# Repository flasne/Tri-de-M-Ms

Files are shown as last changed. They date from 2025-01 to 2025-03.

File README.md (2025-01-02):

# Tri-de-M-Ms

# Introduction à l'IA avec un Trieur de Couleurs pour M&M's

#Les fichiers sont sur le site [Tri-de-M-Ms](https://github.com/flasne/Tri-de-M-Ms)

## 1. Introduction Générale

- **Objectifs du cours :**
  - Comprendre les concepts de base de l'IA et leur application dans un projet concret.
- **Présentation du projet :**
  - Créer un trieur de couleurs pour des M&M's à l'aide d'un Raspberry Pi, avec une progression de techniques (classiques à IA avancée).
- **Rappel des prérequis :**
  - Notions de base en Python.
  - Compréhension des capteurs et actionneurs utilisés avec le Raspberry Pi.
  - Contexte des couleurs : spectres lumineux et perception RVB.

---

## 2. Approche Classique : Analyse des Écarts de Valeurs Mesurées

- **Principe de la méthode :**
  - Comparer les valeurs RVB mesurées par un capteur à des seuils prédéfinis pour classer les couleurs.

### Matériel nécessaire :
- Raspberry Pi.
- Capteur de couleur (TCS34725 ou équivalent).
- Servo-moteur pour trier les M&M's.

### Étapes :
1. **Mesurer les couleurs :** Exploiter le capteur pour obtenir des valeurs RVB des M&M's.
2. **Définir les seuils :** Établir une gamme de valeurs pour chaque couleur (rouge, vert, bleu, jaune).
3. **Programmer la logique conditionnelle :** Utiliser des instructions `if-else` pour diriger les M&M's vers des emplacements spécifiques.

### Limites de l'approche classique :
- Sensibilité aux variations de lumière.
- Difficulté à généraliser.

---

## 3. Introduction aux Modèles d'IA Classiques

- **Principe :**
  - Remplacer la logique conditionnelle par un modèle d'IA entraîné pour classer les couleurs.
  
### Modèles abordés :
- Régression logistique.
- Forêt aléatoire.
- k-Nearest Neighbors (k-NN).

### Étapes :
1. **Collecte de données :** Créer un dataset en mesurant des valeurs RVB et en annotant manuellement les couleurs.
2. **Entraînement des modèles :** Utiliser une bibliothèque comme `scikit-learn` pour entraîner un modèle sur les données collectées.
3. **Évaluation :** Comparer les performances des différents modèles sur des M&M's non vus pendant l'entraînement.
4. **Implémentation :** Intégrer le modèle choisi dans le programme pour trier les M&M's en temps réel.

### Discussion :
- **Avantages de l'IA sur les seuils fixes :** Meilleure adaptabilité et robustesse.

---

## 4. Exemple Avancé : Introduction au Deep Learning

- **Principe :**
  - Utiliser un réseau de neurones pour classer les couleurs avec davantage de flexibilité.

### Matériel et outils :
- Raspberry Pi (avec un accélérateur comme Google Coral pour le traitement en temps réel, si possible).
- Bibliothèque `TensorFlow` ou `PyTorch`.

### Étapes :
1. **Collecte et augmentation des données :** Capturer un dataset plus large, inclure des variations de luminosité, bruit, etc.
2. **Création d’un modèle simple :** Un réseau à plusieurs couches (MLP) pour traiter les données RVB.
3. **Entraînement :** Utiliser un ordinateur pour entraîner le modèle, puis déployer sur le Raspberry Pi.
4. **Optimisation :** Discuter des outils comme TensorFlow Lite pour optimiser le modèle pour l'embarqué.
5. **Évaluation finale :** Comparer les performances du deep learning avec les modèles classiques.

### Discussion :
- **Applications pratiques :** Tri automatisé dans l'industrie, reconnaissance d'images, domotique.
- **Limites :** Temps d'entraînement, besoin en données.

---

## 5. Conclusion et Ouverture

- **Résumé :**
  - Évolution des techniques : classique → modèles d'IA → deep learning.
  - Avantages et inconvénients de chaque approche.
- **Applications réelles :** Tri automatisé dans l'industrie, reconnaissance d'images, domotique.
- **Prolongements :** Intégrer des caméras pour détecter les formes ou textures en complément des couleurs.
- **Questions et perspectives :** Comment améliorer le modèle avec plus de données ou d'autres capteurs ?

---

## 6. Annexes et Ressources

- **Code Python :** Scripts pour chaque étape.
- **Datasets :** Exemples pour tester les modèles.
- **Références :**
  - Documentation scikit-learn.
  - Guides TensorFlow Lite.
  - Ressources pédagogiques complémentaires.

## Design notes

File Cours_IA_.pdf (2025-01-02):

| Initiation à l’intelligence artificielle. Application à un trieur de M&Ms | Animation
GIPTIC SII | Application au trieur de M&Ms | Page 1 sur 44

## Introduction à l'IA avec un trieur de couleurs pour M&M's

### 1. Introduction générale

- Objectifs du cours : Comprendre les concepts de base de l'IA et leur application dans un projet concret.
- Présentation du projet : Créer un trieur de couleurs pour des M&M's à l'aide d'un Raspberry Pi, avec une progression de techniques (classiques à IA avancée).
- Rappel des prérequis :
- Notions de base en Python.
- Compréhension de capteurs et d'actionneurs utilisés avec le Raspberry Pi.
- Contexte des couleurs : spectres lumineux et perception RVB.

### 2. Approche classique : Analyse des écarts de valeurs mesurées

Principe de la méthode : Comparer les valeurs RVB mesurées par un capteur à des seuils prédéfinis pour classer les couleurs.

- Matériel nécessaire :
- Raspberry Pi.
- Capteur de couleur (TCS34725 ou équivalent).
- Servo-moteur pour trier les M&M's.
- Étapes :
1. Mesurer les couleurs : Exploiter le capteur pour obtenir des valeurs RVB des M&M's.
2. Définir les seuils : Établir une gamme de valeurs pour chaque couleur (rouge, vert, bleu, jaune).
3. Programmer la logique conditionnelle : Utiliser des instructions if-else pour diriger les M&M's vers des emplacements spécifiques.
- Limites de l'approche classique : Sensibilité aux variations de lumière, difficulté à généraliser.

### 3. Introduction aux modèles d'IA classiques

- Principe : Remplacer la logique conditionnelle par un modèle d'IA entraîné pour classer les couleurs.
- Modèles abordés :
- Régression logistique.
- Forêt aléatoire.
- k-Nearest Neighbors (k-NN).
- Étapes :
1. Collecte de données : Créer un dataset en mesurant des valeurs RVB et en annotant manuellement les couleurs.
2. Entraînement des modèles : Utiliser une bibliothèque comme scikit-learn pour entraîner un modèle sur les données collectées.
3. Évaluation : Comparer les performances des différents modèles sur des M&M's non vus pendant l'entraînement.
4. Implémentation : Intégrer le modèle choisi dans le programme pour trier les M&M's en temps réel.
- Discussion : Avantages de l'IA sur les seuils fixes (meilleure adaptabilité, robustesse).

GIPTIC SII | Application au trieur de M&Ms | Page 2 sur 44

### 4. Exemple avancé : Introduction au deep learning

- Principe : Utiliser un réseau de neurones pour classer les couleurs avec davantage de flexibilité.
- Matériel et outils :
- Raspberry Pi (avec accélérateur comme Google Coral pour le traitement en temps réel, si possible).
- Bibliothèque TensorFlow ou PyTorch.
- Étapes :
1. Collecte et augmentation des données : Capturer un dataset plus large, inclure des variations de luminosité, bruit, etc.
2. Création d’un modèle simple : Un réseau à plusieurs couches (MLP) pour traiter les données RVB.
3. Entraînement : Utiliser un ordinateur pour entraîner le modèle, puis déployer sur le Raspberry Pi.
4. Optimisation : Discuter des outils comme TensorFlow Lite pour optimiser le modèle pour l'embarqué.
5. Évaluation finale : Comparer les performances du deep learning avec les modèles classiques.
- Discussion : Applications pratiques du deep learning et limites (temps d'entraînement, besoin en données).

### 5. Conclusion et ouverture

- Résumé :
- Évolution des techniques : classique → modèles d'IA → deep learning.
- Avantages et inconvénients de chaque approche.
- Applications réelles : Tri automatisé dans l'industrie, reconnaissance d'images, domotique.
- Prolongements : Possibilité d'intégrer des caméras pour détecter les formes ou textures en complément des couleurs.
- Questions et perspectives : Comment améliorer le modèle avec plus de données ou d'autres capteurs ?

### 6. Annexes et ressources

- Code Python pour chaque étape.
- Datasets exemples pour tester les modèles.
- Références pédagogiques et documentations (scikit-learn, TensorFlow Lite, etc.).

GIPTIC SII | Application au trieur de M&Ms | Page 3 sur 44

## 1. INTRODUCTION GENERALE

Contexte des couleurs : Spectres lumineux et perception RVB

## 1.1. La nature de la lumière et des couleurs

- La lumière visible :
La lumière est une onde électromagnétique, et la partie visible par l’œil humain correspond à une gamme de longueurs d’onde allant de 400 nm (violet) à 700 nm (rouge).
- Spectre lumineux :
Chaque couleur correspond à une longueur d'onde particulière. Par exemple :
- Violet : ~400-450 nm
- Bleu : ~450-495 nm
- Vert : ~495-570 nm
- Jaune : ~570-590 nm
- Rouge : ~620-700 nm
- Couleurs perçues :
La couleur que nous voyons est le résultat de la lumière réfléchie par un objet. Un objet jaune, par exemple, absorbe les longueurs d'onde dans le bleu et réfléchit celles correspondant au jaune.

## 1.2. La perception des couleurs par l'œil humain

- Les photorécepteurs :
L’œil humain possède trois types de cônes sensibles aux longueurs d’onde :
- Cônes L (longueurs d'onde longues, rouge)
- Cônes M (longueurs d'onde moyennes, vert)
- Cônes S (longueurs d'onde courtes, bleu)

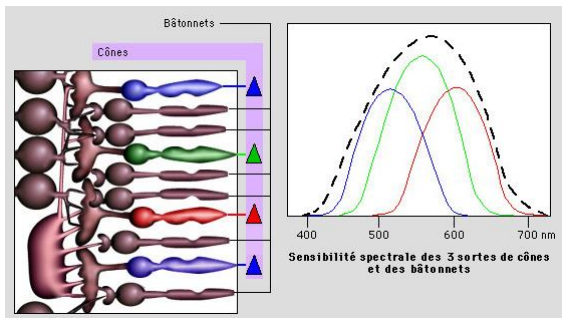
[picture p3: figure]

- Mélange additif des couleurs :
L'œil humain perçoit une couleur en combinant les signaux des cônes L, M, et S. Par exemple :
- Rouge + Vert → Jaune

GIPTIC SII | Application au trieur de M&Ms | Page 4 sur 44
- Rouge + Bleu → Magenta
- Vert + Bleu → Cyan
- Rouge + Vert + Bleu → Blanc

## 1.3. Modèle RVB (Rouge, Vert, Bleu) RGB

- Définition :
Le modèle RGB est un système de représentation des couleurs basé sur la perception humaine. Chaque couleur est définie par une combinaison de trois valeurs (R, G, B), chacune représentant l'intensité lumineuse dans une des trois bandes : rouge, vert, bleu.
- Plage des valeurs :
Typiquement, les valeurs RGB vont de 0 (aucune lumière) à 255 (intensité maximale), formant une palette de plus de 16 millions de couleurs.
Exemple :
- Rouge pur : (255, 0, 0)
- Vert pur : (0, 255, 0)
- Bleu pur : (0, 0, 255)
- Blanc : (255, 255, 255)
- Noir : (0, 0, 0)
- Applications dans le projet :
Les capteurs de couleur (comme le TCS34725) mesurent les valeurs RVB d’un objet en analysant la lumière réfléchie par celui-ci et en la décomposant en trois composantes (R, G, B).

## 1.4. Variabilité des mesures RVB

- Facteurs influençant les mesures :
- Source lumineuse : La couleur perçue peut changer selon la lumière ambiante (naturelle, LED, etc.).
- Réflectance de la surface : Les objets brillants ou mats n’interagissent pas de la même manière avec la lumière.
- Position et distance du capteur : La mesure peut varier en fonction de l’angle ou de la distance entre le capteur et l’objet.
- Importance de la calibration :
Pour garantir des mesures précises et cohérentes, il est souvent nécessaire de calibrer le capteur avec des couleurs de référence avant de commencer le tri.

GIPTIC SII | Application au trieur de M&Ms | Page 5 sur 44

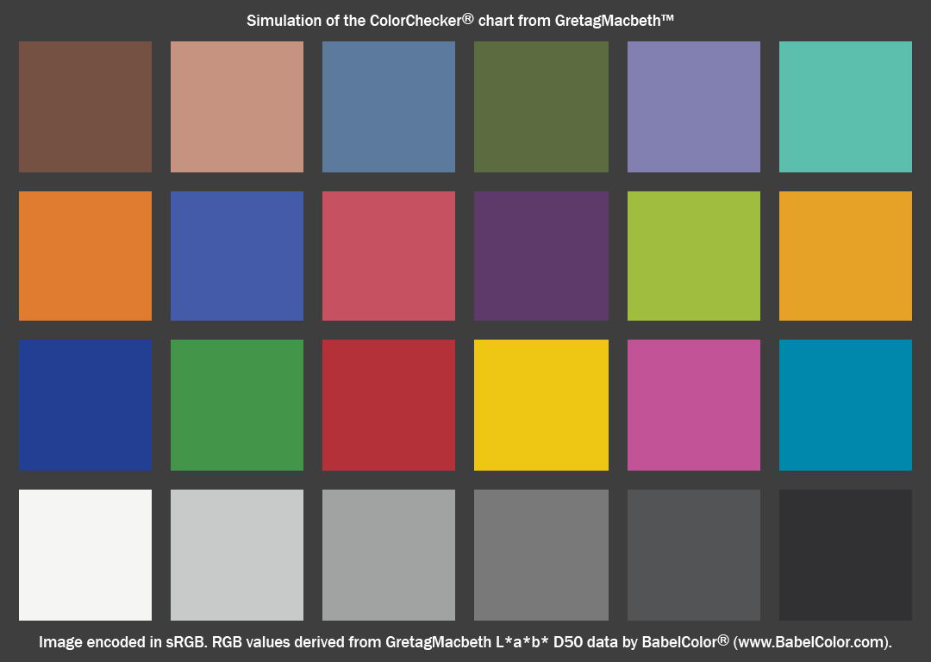
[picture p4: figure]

## 1.5. Illustration pratique pour le projet

- Exemple de mesure :

Un M&M rouge pourrait donner les valeurs approximatives suivantes :
- Rouge : 200
- Vert : 50
- Bleu : 40

Un M&M jaune, en revanche, pourrait donner :

- Rouge : 180
- Vert : 170
- Bleu : 50
- Analyse :
Les valeurs mesurées permettent de distinguer les couleurs des M&M's et de les classer en fonction de seuils ou via des modèles IA.

Fonctionnement succinct du capteur de couleur TCS34725

Le TCS34725 est un capteur de couleur populaire pour les projets électroniques, notamment avec un Raspberry Pi ou un Arduino. Voici son fonctionnement résumé :

GIPTIC SII | Application au trieur de M&Ms | Page 6 sur 44

## 1.6. Principe de base

- Détection de lumière réfléchie :
Le capteur utilise un photodétecteur pour mesurer la lumière réfléchie par un objet. Il capte les intensités lumineuses dans trois bandes spectrales principales : rouge (R), vert (G), et bleu (B), ainsi qu’une composante luminance totale (canal clair).

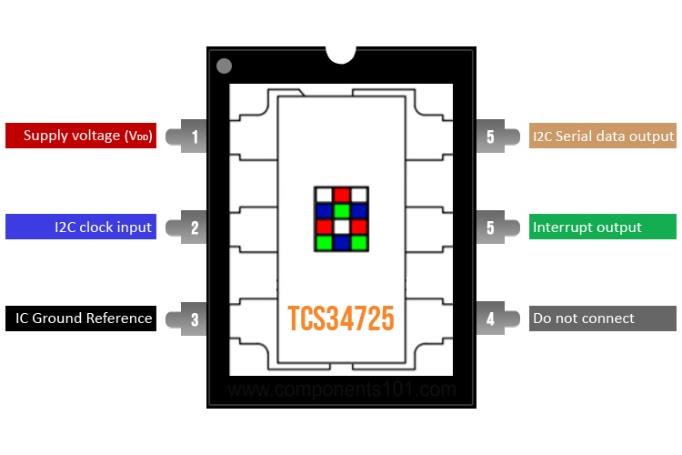
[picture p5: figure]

- Éclairage intégré :

Le TCS34725 possède une LED blanche intégrée pour fournir un éclairage constant, améliorant la précision des mesures indépendamment des conditions lumineuses ambiantes.

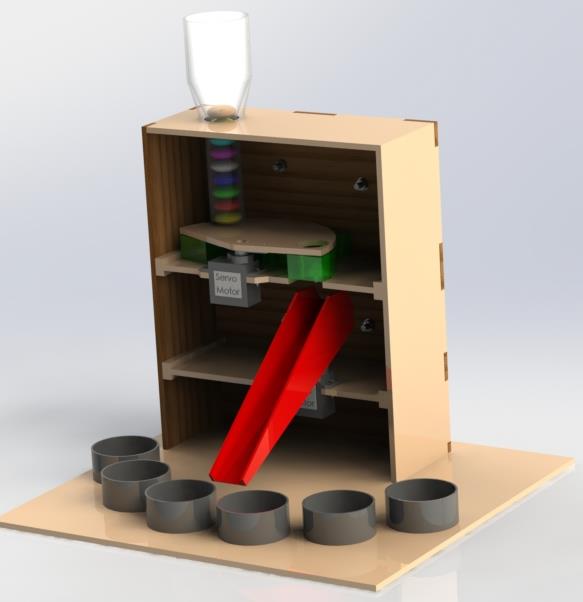
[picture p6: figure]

## 1.7. Composants principaux

- Filtre passe-bande :
Un filtre intégré isole les longueurs d'onde correspondant aux couleurs rouge, verte, et bleue.
- Photodiodes :
Chaque photodiode est dédiée à une bande de fréquence (R, G, B, et clair). Elles transforment la lumière incidente en signaux électriques proportionnels à l’intensité lumineuse.
- Convertisseur analogique-numérique (ADC) :
Le capteur convertit les signaux analogiques en valeurs numériques exploitables via un microcontrôleur ou un ordinateur (Raspberry Pi, par exemple).

GIPTIC SII | Application au trieur de M&Ms | Page 7 sur 44

## 1.8. Interface et communication

- Protocole I2C :
Le TCS34725 communique via le protocole I2C, ce qui facilite son intégration avec des
microcontrôleurs ou des
ordinateurs monocarte comme le Raspberry Pi.
- Commande logicielle :
Les bibliothèques comme Adafruit TCS34725 (en Python) simplifient son utilisation en fournissant des fonctions pour lire les valeurs
RVB et calibrer le capteur.

## 1.9. Avantages

- Compact, précis et facile à utiliser.

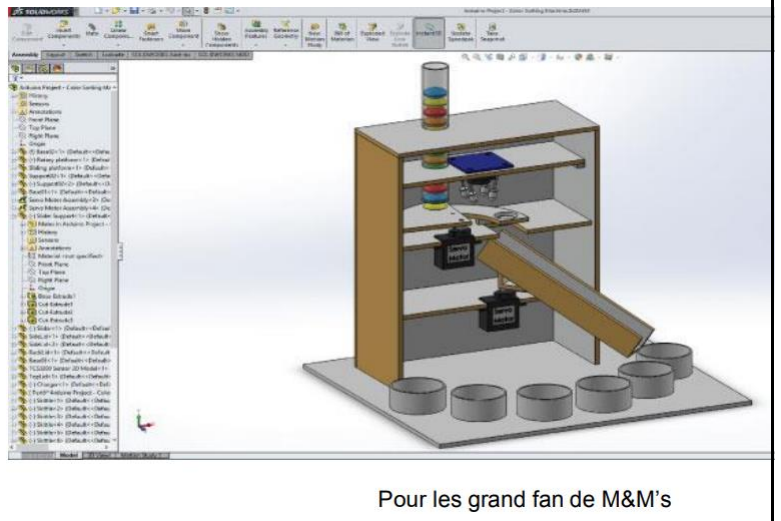
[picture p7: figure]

- LED intégrée pour garantir des mesures constantes.
- Compatible avec de nombreux environnements de développement (Arduino, Raspberry Pi).

## 1.10 Installation des paquets

pip install smbus2
sudo apt install -y python3-pyqt5 python3-opengl python -m pip install scipy
python -m pip install numpy
python -m pip install matplotlib
python -m pip install sklearn
python -m pip install pandas
pip3 install -U scikit-learn scipy matplotlib pip install pandas tensorflow scikit-learn joblib

## 2. APPROCHE CLASSIQUE : ANALYSE DES ECARTS DE VALEURS MESUREES

On utilise pour répondre au cahier des charge deux servo moteur :

Les servos sont câblés sur les sortie GPIO 17 bas et 18 haut

1. Servo 1 : avec trois positions :
- Position 1 : Chargement.
- Position 2 : Mesure.
- Position 3 : Éjection.

GIPTIC SII | Application au trieur de M&Ms | Page 8 sur 44
2. Servo 2 :
- 6 positions pour trier les M&M’s par couleur : marron, vert, orange, jaune, rouge, bleu.

Pour une meilleure gestion des servos moteurs utilisation de la librairie pigpiod pour les raspberry < P5

https://abyz.me.uk/rpi/pigpio/download.html

wget https://github.com/joan2937/pigpio/archive/master.zip unzip master.zip
cd pigpio-master
make
sudo make install

## Bus I2C

Le capteur de couleur sur le bus I2C, activer le bus I2C pour le raspberry et vérifier la présence du capteur sudo apt-get install i2c-tools
sudo i2cdetect -y 1

adresse #39 pour APDS-9960 Digital Proximity, Ambient Light, RGB and Gesture Sensor

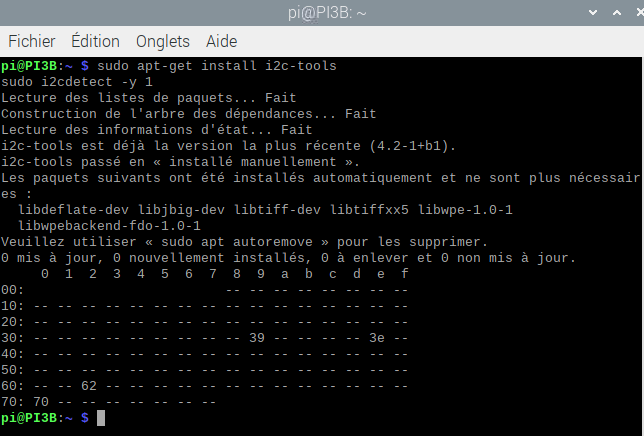
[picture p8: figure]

## 2.1 Câblage et simulation exemple en Micropython et WOKWI

GIPTIC SII | Application au trieur de M&Ms | Page 9 sur 44

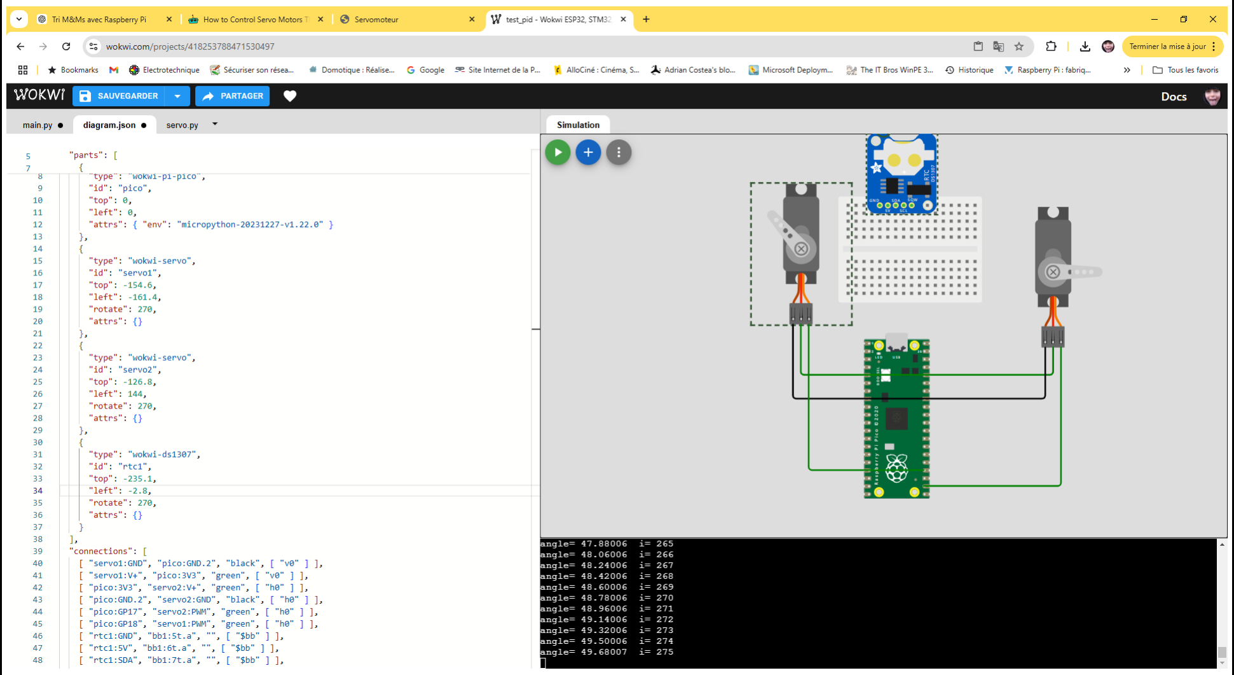
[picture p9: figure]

### 2.2 Création d’un fichier CSV pour les échantillons

Programme pour collecter des échantillons de données et générer un fichier CSV contenant les valeurs RGB mesurées pour 10 pastilles de chaque couleur. Le programme suit un cycle itératif où vous insérez les pastilles par couleur et validez chaque échantillon. Le fichier CSV sera généré après la collecte de tous les échantillons sous le nom :

couleurs_echantillons.csv

Programme Python

from gpiozero import Servo
from time import sleep
from gpiozero.pins.pigpio import PiGPIOFactory import smbus
import csv

factory = PiGPIOFactory()

servoh = Servo(18, min_pulse_width=0.56, max_pulse_width=1.85, pin_factory=factory)
servob = Servo(17, min_pulse_width=0.52, max_pulse_width=1.8 , pin_factory=factory)

# Configuration I2C

bus = smbus.SMBus(1)

GIPTIC SII | Application au trieur de M&Ms | Page 10 sur 44

SENSOR_ADDRESS = 0x39

# Définir le chemin du fichier CSV

nom_fichier = "couleurs.csv"

# Liste des couleurs et structure pour stocker les données COULEURS = ["bleu", "rouge", "vert", "marron", "jaune", "orange"] echantillons = {couleur: [] for couleur in COULEURS}

# Initialisation du capteur

def init_sensor():
bus.write_byte_data(SENSOR_ADDRESS, 0x00 | 0x80, 0x03)
bus.write_byte_data(SENSOR_ADDRESS, 0x07 | 0x80, 0x00)

# Lecture des données RGB

def read_colors():
bus.write_byte_data(SENSOR_ADDRESS, 0x00 | 0x80, 0x03)
sleep(0.5)
data = bus.read_i2c_block_data(SENSOR_ADDRESS, 0x10 | 0x80, 8)
green = data[1] * 256 + data[0]
red = data[3] * 256 + data[2]
blue = data[5] * 256 + data[4]

# ajustement pour fond noir red -= 19.00

green -= 35
blue -= 16

return red, green, blue

# Collecte des données pour une couleur spécifique

def collect_sample(couleur, num_samples=10): print(f"Insérez des pastilles de couleur '{couleur}'.") for i in range(num_samples):
print(f"Mesure {i + 1}/{num_samples} pour {couleur}.") print("Position de mesure...")
servoh.mid()
sleep(1)
red, green, blue = read_colors() echantillons[couleur].append((red, green, blue)) print(f"R: {red}, G: {green}, B: {blue} enregistré pour {couleur}.")

print("Position de dechargement...")
servoh.max()
sleep(1)

print("Position de chargement...") servoh.min()

GIPTIC SII | Application au trieur de M&Ms | Page 11 sur 44

sleep(3)

# Enregistrement des données dans un fichier CSV

def save_to_csv():
with open(nom_fichier, 'w', newline='', encoding='utf-8') as fichier_csv:
file = csv.writer(fichier_csv)
file.writerow(["Couleur", "Red", "Green", "Blue"]) # En-têtes for couleur, samples in echantillons.items():
for red, green, blue in samples:
file.writerow([couleur, red, green, blue]) print(f"Données enregistrées dans {nom_fichier}.")

# Programme principal

def main():
try:
init_sensor()
servoh.mid()
servob.mid()
for couleur in COULEURS:
collect_sample(couleur)
save_to_csv()
except KeyboardInterrupt:
print("Programme interrompu.") finally:
servoh.value = None
servob.value = None
print("Servos désactivés. Fin du programme.")

if __name__ == "__main__": main()

Fonctionnement

1. Initialisation :
- Le capteur et les servos sont initialisés dans les positions par défaut.
2. Collecte des Échantillons :
- Pour chaque couleur dans la liste COULEURS, le programme lit les données RGB pour 10 pastilles (ou une valeur ajustable dans num_samples).
- Entre chaque lecture, le servo horizontal (servoh) est déplacé pour simuler la position de mesure de déchargement et de chargement.
3. Enregistrement des Données :
- Une fois toutes les pastilles mesurées, les données sont enregistrées dans un fichier CSV avec des colonnes pour la couleur et les valeurs RGB.
4. Arrêt Sécurisé :
- Les servos sont désactivés et retournent à leur état neutre à la fin ou en cas d'interruption.

Détermination des plages de couleurs à partir des échantillons

GIPTIC SII | Application au trieur de M&Ms | Page 12 sur 44

Programme Python

import csv

# Fonction pour calculer les plages de variation des couleurs def calculate_color_ranges(file_path):

color_data = {}

# Lecture du fichier CSV

with open(file_path, 'r', encoding='utf-8') as csvfile: reader = csv.reader(csvfile)
next(reader) # Ignorer les en-têtes
for row in reader:
r, g, b, color = float(row[0]), float(row[1]), float(row[2]), row[3]
if color not in color_data:
color_data[color] = {"R": [], "G": [], "B": []} color_data[color]["R"].append(r) color_data[color]["G"].append(g) color_data[color]["B"].append(b)

# Calcul des plages pour chaque couleur color_ranges = {}

for color, channels in color_data.items(): color_ranges[color] = {
"R": (min(channels["R"]), max(channels["R"])), "G": (min(channels["G"]), max(channels["G"])), "B": (min(channels["B"]), max(channels["B"])) }

return color_ranges

# Fonction principale

def main():
file_path = "couleurs_echantillons.csv" # Remplacez par le chemin de votre fichier CSV
color_ranges = calculate_color_ranges(file_path)

print("Plages de variation des couleurs :")
for color, ranges in color_ranges.items(): print(f"{color.capitalize()} :")
print(f" | R (Rouge) : {ranges['R']}")
print(f" | G (Vert) | : {ranges['G']}")
print(f" | B (Bleu) | : {ranges['B']}")

# Exécution du script

if __name__ == "__main__": main()

GIPTIC SII | Application au trieur de M&Ms | Page 13 sur 44

Fonctionnement

- Lecture des données CSV :
Le fichier CSV est lu ligne par ligne, et les valeurs RGB associées à chaque couleur sont stockées dans un dictionnaire.
- Calcul des plages de variation :
Pour chaque couleur, les valeurs minimales et maximales de R, G et B sont déterminées.
- Affichage des résultats :
Les plages de variation pour chaque couleur sont imprimées de manière lisible.

Résultat
| R | | G | | B
| min | max | min | max | min | max
Color
bleu | 0.0 | 1.0 | 0.0 | 1.0 | 4.0 | 5.0
jaune | 10.0 | 12.0 | 10.0 | 12.0 | 2.0 | 2.0
marron | 1.0 | 1.0 | -2.0 | -1.0 | 0.0 | 0.0
orange | 8.0 | 10.0 | 3.0 | 4.0 | 1.0 | 1.0
rouge | 6.0 | 7.0 | 0.0 | 1.0 | 0.0 | 1.0
vert | 1.0 | 2.0 | 4.0 | 5.0 | 2.0 | 2.0

Utilisation

COLOR_RANGES = {
"bleu": [(0.0, 0.0), (1.0, 2.0), (4.0, 5.0)], "rouge": [(6.0, 7.0), (0.0, 1.0), (1.0, 1.0)], "vert": [(2.0, 2.0), (5.0, 6.0), (2.0, 2.0)], "marron": [(0.0, 1.0), (-1.0, -1.0), (0.0, 1.0)], "jaune": [(10.0, 12.0), (10.0, 13.0), (2.0, 3.0)], "orange": [(9.0, 11.0), (4.0, 5.0), (1.0, 2.0)], }

Réalisation du programme de tri en prenant en compte des variations avec une pondération de 1

Programme Python

'''
lancer

sudo pigpiod

avant
'''

from gpiozero import Servo

GIPTIC SII | Application au trieur de M&Ms | Page 14 sur 44

from time import sleep

from gpiozero.pins.pigpio import PiGPIOFactory

import smbus
import time
import csv
import joblib

factory = PiGPIOFactory()

servoh = Servo(18, min_pulse_width=0.56/1000, max_pulse_width=1.85/1000, pin_factory=factory) servob = Servo(17, min_pulse_width=0.52/1000, max_pulse_width=1.8/1000, pin_factory=factory)

servob_POSITIONS = {
"marron": -0.3, | # Position pour marron
"vert": 0.6, | # Position pour vert
"orange": -0.95, | # Position pour orange
"jaune": -0.7, | # Position pour jaune
"rouge": 0.1, | # Position pour rouge
"bleu": 0.9 | # Position pour bleu
}

COLOR_RANGES = {
"bleu": [(0.0, 0.0), (1.0, 2.0), (4.0, 5.0)], "rouge": [(6.0, 7.0), (0.0, 1.0), (1.0, 1.0)], "vert": [(2.0, 2.0), (5.0, 6.0), (2.0, 2.0)], "marron": [(0.0, 1.0), (-1.0, -1.0), (0.0, 1.0)], "jaune": [(10.0, 12.0), (10.0, 13.0), (2.0, 3.0)], "orange": [(9.0, 11.0), (4.0, 5.0), (1.0, 2.0)], }

# Get I2C bus

bus = smbus.SMBus(1)

# Initialisation du capteur def init_sensor():

# Initialisation du capteur

# TCS3414 address, 0x39(57)

# Select control register, 0x00(00), with Command register, 0x80(128)

# | 0x03(03) | Power ON, ADC enable

bus.write_byte_data(0x39, 0x00 | 0x80, 0x03)

GIPTIC SII | Application au trieur de M&Ms | Page 15 sur 44

# Lecture des données de couleur

def read_colors():
global rang
bus.write_byte_data(0x39, 0x00 | 0x80, 0x03)
# TCS3414 address, 0x39(57)

# Select gain register, 0x07(07), with Command register, 0x80(128)

# | 0x00(00) | Gain : 1x, Prescaler Mode = Divide by 1

bus.write_byte_data(0x39, 0x07 | 0x80, 0x00)
time.sleep(0.5)
# TCS3414 address, 0x39(57)

# Read data back from 0x10(16), 8 bytes, with Command register, 0x80(128)

# Green LSB, Green MSB, Red LSB, Red MSB

# Blue LSB, Blue MSB, cData LSB, cData MSB

data = bus.read_i2c_block_data(0x39, 0x10 | 0x80, 8)
# Convert the data

green = data[1] * 256 + data[0]
red = data[3] * 256 + data[2]
blue = data[5] * 256 + data[4]
cData = data[7] * 256 + data[6]
# Calculate luminance

luminance = (-0.32466 * red) + (1.57837 * green) + (-0.73191 * blue)

red -= 19.00
green -= 35.00
blue -= 16.00

return cData, red, green, blue

# Déterminer la couleur dominante def detect_color():

_, r, g, b = read_colors()
print(f"R: {r}, G: {g}, B: {b}")
tolerance = 1
for color, (r_range, g_range, b_range) in COLOR_RANGES.items(): if (
(r_range[0] - tolerance) <= r <= (r_range[1] + tolerance) and
(g_range[0] - tolerance) <= g <= (g_range[1] + tolerance) and
(b_range[0] - tolerance) <= b <= (b_range[1] + tolerance)
):
return color
return "inconnu"

GIPTIC SII | Application au trieur de M&Ms | Page 16 sur 44

# Trier les M&M’s

def tri_m_and_ms():
while True:
print("Passage en position de chargement...") servoh.min()
sleep(1)
print("Passage en position de mesure...") servoh.mid()
couleur = detect_color()
print(f"Couleur détectée : {couleur}")
# Pause pour éviter des lectures rapides sleep(1)

if couleur in servob_POSITIONS:
print(f"Tri pour {couleur}...") servob.value = servob_POSITIONS[couleur] #control_servo(SERVO1_GPIO, SERVO1_POSITIONS["ejection"]) # Éjection après tri sleep(0.5)
servoh.max()
else:
print("Couleur inconnue, ignorer l'objet") # Pause pour éviter des lectures rapides sleep(1)
servob.value = 0

# Programme principal

print("Start in the middle") servoh.mid()
servob.mid()
rang=1
try:
init_sensor()
tri_m_and_ms()
except KeyboardInterrupt:
print("Arrêt du programme.")

Fonctionnement

1. Servo 1 :
- Change entre 3 positions (chargement, mesure, éjection) pour gérer le flux des M&M’s.
- Les angles pour chaque position sont définis dans max mid et min.
2. Servo 2 :
- Positionné selon la couleur détectée : marron, vert, orange, jaune, rouge, ou bleu.
- Les angles pour chaque couleur sont définis dans SERVO2_POSITIONS.
3. Détection des couleurs :

GIPTIC SII | Application au trieur de M&Ms | Page 17 sur 44
- Les couleurs sont détectées en comparant les valeurs de rouge, vert et bleu. Des seuils sont définis pour certaines couleurs complexes comme jaune, orange ou marron.
4. Tri :
- Le premier servo gère le déplacement des M&M’s entre les étapes.
- Le second servo place les M&M’s dans le compartiment correspondant.

Ajustements et Tests

- Calibrage des seuils de couleur : Ajustez les seuils selon les valeurs spécifiques des couleurs obtenues par votre capteur.
- Angles des servos : Modifiez les valeurs pour les adapter à votre configuration matérielle.

Constations avec une tolérance de :

### 0 les couleurs ont du mal à être détectées en fonction des variations d’éclairage

### 1 le tri est parfait aucune erreur, fin de la manipe (non !)

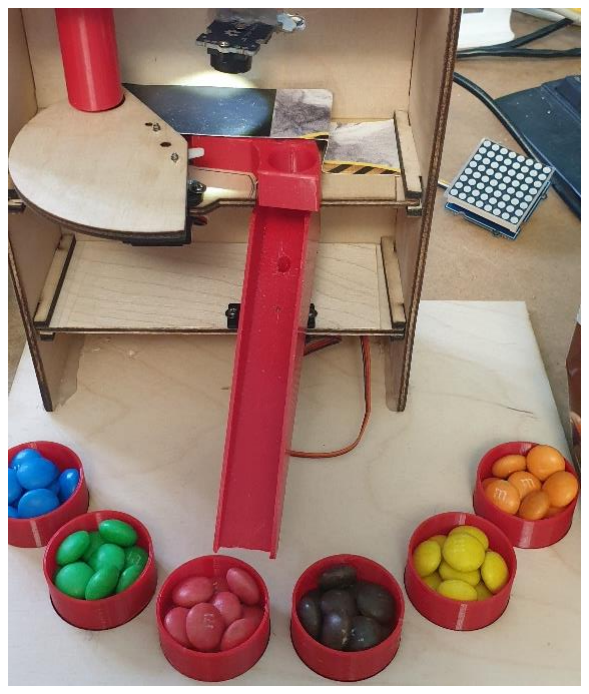
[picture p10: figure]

Avec une tolérance de 2 il y a une confusion entre les bleus et vert et entre les rouges et oranges.

GIPTIC SII | Application au trieur de M&Ms | Page 18 sur 44

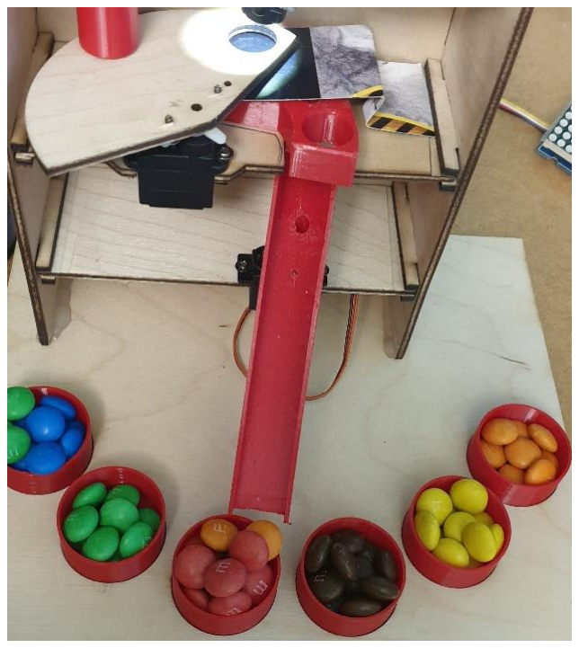
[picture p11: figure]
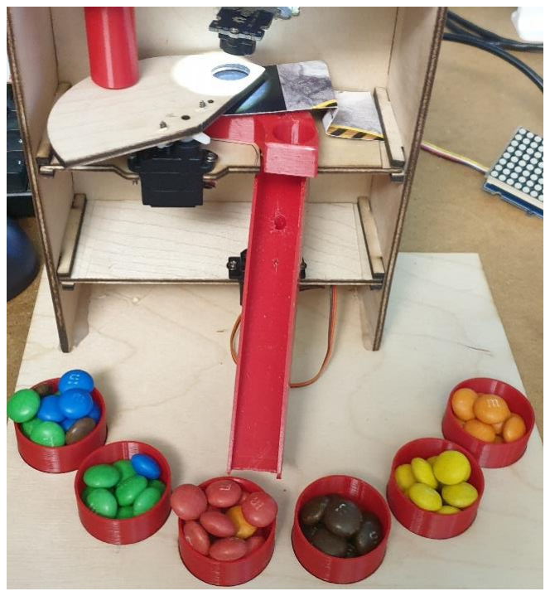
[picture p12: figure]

## 3. INTRODUCTION AUX MODELES D'IA CLASSIQUES

- 3.1 Principe :

Remplacer la logique conditionnelle par un modèle d'IA entraîné pour classer les couleurs.

- 3.2 Modèles abordés :
- Régression logistique. LR
- Forêt aléatoire.
- k-Nearest Neighbors (k-NN).

### 3.2.1. Régression logistique

Principe

- La régression logistique est un modèle statistique utilisé pour résoudre des problèmes de classification binaire ou multi-classes.
- Fonctionnement : Elle modélise la probabilité qu'une observation appartienne à une classe donnée en utilisant une fonction logistique (sigmoïde).
- Sortie : Les probabilités que l'entrée appartienne à chaque classe. La classe avec la plus grande probabilité est choisie.

Avantages

- Simplicité, rapidité, facile à implémenter.
- Bonne performance sur des données linéairement séparables.

GIPTIC SII | Application au trieur de M&Ms | Page 19 sur 44

Inconvénients

- Ne gère pas bien les relations non linéaires entre les caractéristiques.
- Sensible aux caractéristiques fortement corrélées.

### 3.2.2. Forêt aléatoire (Random Forest)

Principe

- La forêt aléatoire est un ensemble de plusieurs arbres de décision, chacun entraîné sur un sous-ensemble aléatoire des données (méthode de bootstrap) et un sous-ensemble aléatoire des caractéristiques.
- Fonctionnement : Chaque arbre vote pour une classe, et la classe majoritaire est choisie comme prédiction.

Étapes principales

1. Création des arbres :
- Les arbres sont créés en sélectionnant un sous-ensemble aléatoire des échantillons et des caractéristiques.
- Chaque arbre est construit de manière indépendante.
2. Prédiction : Lorsqu'un M&M est mesuré, chaque arbre effectue une prédiction. La classe finale est celle qui obtient le plus de votes.
3. Importance des caractéristiques : La forêt aléatoire peut également identifier quelles caractéristiques (R, G, B) sont les plus importantes pour la classification.

Avantages

- Robuste aux sur-apprentissages grâce à l'agrégation.
- Peut modéliser des relations complexes entre les caractéristiques.
- Pas besoin de normaliser les données d'entrée.

Inconvénients

- Plus lent que des modèles simples comme la régression logistique.
- Moins interprétable qu'un seul arbre de décision.

### 3.2.3. k-Nearest Neighbors (k-NN)

Principe

- Le k-NN est un modèle basé sur les instances. Il classe un nouvel échantillon en fonction des k échantillons les plus proches dans les données d'entraînement.
- Fonctionnement : Il calcule les distances entre l'échantillon à classer et toutes les observations de l'ensemble d'entraînement, puis vote pour la classe la plus fréquente parmi les kkk plus proches voisins.

Étapes principales

GIPTIC SII | Application au trieur de M&Ms | Page 20 sur 44
1. Choix de kkk : kkk est un hyperparamètre qui détermine le nombre de voisins à considérer. Des valeurs courantes sont 3, 5 ou 7.
2. Distance : La distance est souvent calculée à l’aide de la distance euclidienne : d=(R1−R2)2+(G1−G2)2+(B1−B2)2d = \sqrt{(R_1 - R_2)^2 + (G_1 - G_2)^2 + (B_1 -B_2)^2}d=(R1−R2)2+(G1−G2)2+(B1−B2)2
3. Classification : Les kkk voisins les plus proches sont identifiés, et l’étiquette majoritaire est attribuée.

Avantages

- Facile à comprendre et à implémenter.
- Aucune phase d’entraînement explicite, ce qui le rend très rapide en préparation.

Inconvénients

- Coût computationnel élevé pour les prédictions sur de grands ensembles de données (doit calculer la distance avec toutes les instances).
- Sensible à l’échelle des caractéristiques (les données doivent être normalisées si les échelles diffèrent).

Conclusion

- Régression logistique : Utilisée en première approche si les données sont simples et bien séparées.
- Forêt aléatoire : Idéal pour des problèmes plus complexes avec des interactions entre les caractéristiques.
- k-NN : Bon pour débuter ou si le jeu de données est petit, mais moins adapté pour des ensembles volumineux.

Ces trois modèles permettent une introduction progressive à l’IA et montrent comment des approches différentes peuvent résoudre un même problème de classification.

On peut tester également

LDA
Naïve Bayes
SVM

### 3.2.4 Analyse discriminante linéaire (LDA)

- Classe utilisée : LinearDiscriminantAnalysis
- Principe : LDA trouve des combinaisons linéaires de caractéristiques qui maximisent la séparation entre les classes.
- Avantage : Convient aux problèmes où les distributions des classes suivent une loi normale.

GIPTIC SII | Application au trieur de M&Ms | Page 21 sur 44
- Utilisation : Bonne alternative à la régression logistique lorsque les classes sont bien séparées.

### 3.2.5 Machine à vecteurs de support (SVM)

- Classe utilisée : SVC
- Gamma : Détermine l’influence d’un seul point d’entraînement. Avec gamma='auto', cette influence est ajustée automatiquement.
- Principe : Cherche à maximiser la marge entre les classes en utilisant des hyperplans. Peut être étendu à des problèmes non linéaires avec des noyaux (kernel).
- Avantage : Performant pour les données complexes.
- Inconvénient : Lent pour les grands jeux de données.

### 3.2.6 Naïve Bayes (NB)

- Classe utilisée : GaussianNB
- Principe : Utilise le théorème de Bayes en supposant que les caractéristiques sont indépendantes (hypothèse naïve).
- Particularité : Convient aux données où chaque classe suit une distribution gaussienne.
- Avantage : Rapide et performant pour des données simples.
- Inconvénient : Hypothèse d'indépendance souvent irréaliste.

Résumé : Quand utiliser quel modèle ?

Modèle | Complexité | Données linéaires | Données non
linéaires | Interprétabilité Rapidité
Régression logistique Faible | Oui | Non | Élevée | Rapide
LDA | Moyenne | Oui | Non | Moyenne | Moyenne
k-NN | Faible | Oui | Oui | Moyenne | Lent
Arbre de décision | Moyenne | Oui | Oui | Élevée | Moyenne
Naïve Bayes | Faible | Oui | Non | Moyenne | Rapide
SVM | Élevée | Oui | Oui (avec noyaux) Faible | Lent

Ces modèles permettent une large exploration des approches supervisées pour différents types de données et contraintes.

### 3.3. Quatre étapes à réaliser :

1. Collecte de données : Créer un dataset en mesurant des valeurs RVB et en annotant manuellement les couleurs.
2. Entraînement des modèles : Utiliser une bibliothèque comme scikit-learn pour entraîner un modèle sur les données collectées.
3. Évaluation : Comparer les performances des différents modèles sur des M&M's non vus pendant l'entraînement.

GIPTIC SII | Application au trieur de M&Ms | Page 22 sur 44
4. Implémentation : Intégrer le modèle choisi dans le programme pour trier les M&M's en temps réel.

Etape N°1 collecte des données

Voir 2.2 Création d’un fichier CSV pour les échantillons

Etape N°2 Entraînement des modèles

On choisit six modèles LDA, LR, KNN, CART, NB, et SVM

Réalisation du programme en python Apprentissage_Ai

import pandas as pd
from pandas.plotting import scatter_matrix
from matplotlib import pyplot as plt
from sklearn.model_selection import train_test_split, cross_val_score, StratifiedKFold
from sklearn.linear_model import LogisticRegression
from sklearn.tree import DecisionTreeClassifier
from sklearn.neighbors import KNeighborsClassifier
from sklearn.discriminant_analysis import LinearDiscriminantAnalysis from sklearn.naive_bayes import GaussianNB
from sklearn.svm import SVC
from sklearn.metrics import classification_report, confusion_matrix, accuracy_score
from sklearn.preprocessing import LabelEncoder
import joblib

# === 1. Chargement et exploration des données ===

# Chargement du dataset

file_path = 'couleurs.csv' # Remplacez par le chemin correct try:
dataset = pd.read_csv(file_path)
print("Dataset loaded successfully.")
except FileNotFoundError:
print(f"Error: The file '{file_path}' was not found.") exit()

# Dimensions du dataset

print("Dataset dimensions:", dataset.shape)

# Aperçu des premières lignes

print("First 5 rows:\n", dataset.head())

# Statistiques descriptives

print("Descriptive statistics:\n", dataset.describe())

# Matrice de dispersion des variables

GIPTIC SII | Application au trieur de M&Ms | Page 23 sur 44

scatter_matrix(dataset)
plt.title("Scatter Matrix of Dataset") plt.show()

# === 2. Préparation des données ===

# Séparation des caractéristiques (RVB) et des labels (classe des couleurs)

X = dataset.iloc[:, :3].values | # Colonnes RVB
Y = dataset.iloc[:, 3].values | # Classe de couleur

# Encodage des labels (classes des couleurs) label_encoder = LabelEncoder()

Y_encoded = label_encoder.fit_transform(Y)

# Séparation des données en ensembles d'entraînement et de validation X_train, X_validation, Y_train, Y_validation = train_test_split(

X, Y_encoded, test_size=0.30, random_state=1
)

# === 3. Définition et évaluation des modèles ===

# Liste des modèles à tester

models = [
('LR', LogisticRegression(solver='liblinear', multi_class='ovr')), ('LDA', LinearDiscriminantAnalysis()),
('KNN', KNeighborsClassifier()),
('CART', DecisionTreeClassifier()),
('NB', GaussianNB()),
('SVM', SVC(gamma='auto'))
]

# Comparaison des modèles

results = []
names = []
print("\nModel Evaluation Results:")
for name, model in models:
kfold = StratifiedKFold(n_splits=7, random_state=1, shuffle=True) cv_results = cross_val_score(model, X_train, Y_train, cv=kfold, scoring='accuracy')
results.append(cv_results)
names.append(name)
print(f"{name}: {cv_results.mean():.6f} ({cv_results.std():.6f})")

# Visualisation des performances

plt.boxplot(results, labels=names)
plt.title('Algorithm Comparison') plt.ylabel('Accuracy')
plt.show()

GIPTIC SII | Application au trieur de M&Ms | Page 24 sur 44

# === 4. Entraînement, prédictions et sauvegarde des modèles ===

# Fonction utilitaire pour entraîner, prédire et sauvegarder un modèle def train_and_save_model(model, model_name, X_train, Y_train, X_validation, Y_validation, label_encoder):

model.fit(X_train, Y_train)
predictions = model.predict(X_validation)

# Sauvegarde du modèle et de l'encodeur

joblib.dump(model, f'{model_name}.pkl') joblib.dump(label_encoder, f'label_encoder_{model_name}.pkl')

# Évaluation des performances

print(f"\n=== Results for {model_name} ===") print("Accuracy:", accuracy_score(Y_validation, predictions)) print("Confusion Matrix:\n", confusion_matrix(Y_validation, predictions))
print("Classification Report:\n", classification_report(Y_validation, predictions))

# Entraînement et sauvegarde pour chaque modèle

for name, model in models:
train_and_save_model(model, name, X_train, Y_train, X_validation, Y_validation, label_encoder)

# === Fin du programme ===

print("All models trained and saved successfully.")
1. Chargement des données : Ajout de gestion d'erreur pour s'assurer que le fichier CSV existe avant de continuer.
2. Exploration des données : Ajout d'une matrice de dispersion pour visualiser les relations entre les caractéristiques.
3. Préparation des données : Utilisation explicite de iloc pour séparer les caractéristiques et les labels.
4. Comparaison des modèles : Résultats affichés avec moyenne et écart type. Les graphiques de comparaison sont ajoutés.
5. Entraînement et sauvegarde : Fonction utilitaire pour éviter la duplication de code, avec des évaluations détaillées pour chaque modèle.

Les résultats sont les suivants

LR : 1.000000 (0.000000)
LDA: 1.000000 (0.000000)
KNN: 1.000000 (0.000000)
CART: 0.976190 (0.058321)
NB: 0.952381 (0.075292)

GIPTIC SII | Application au trieur de M&Ms | Page 25 sur 44

SVM: 1.000000 (0.000000)

Matrice de dispersion des variables | Visualisation des performances

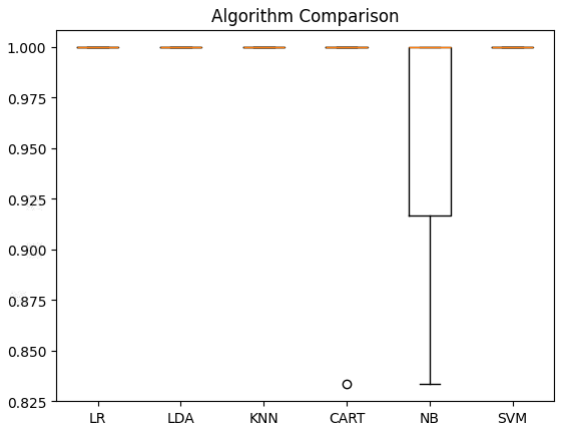
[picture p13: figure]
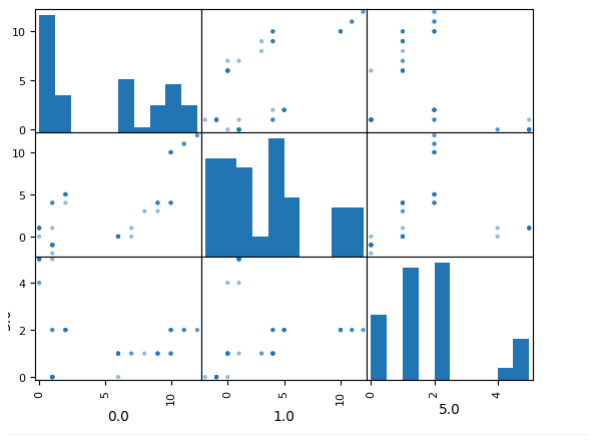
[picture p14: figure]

Les résultats affichés montrent une excellente performance des modèles testés sur le jeu de données.

### 3.4. Performances des modèles :

- Régression Logistique (LR) :
- Score moyen d'exactitude (accuracy) : 1.000000 avec écart-type 0.000000.
- Cela signifie que le modèle a classé toutes les instances correctement, sans variation dans les résultats.
- Analyse Discriminante Linéaire (LDA) :
- Score d'exactitude : 1.000000 (0.000000).
- Comme pour LR, ce modèle est parfait sur ce jeu de données.
- k-Nearest Neighbors (KNN) :
- Score d'exactitude : 1.000000 (0.000000).
- Ce modèle, basé sur les voisins les plus proches, a également obtenu une performance parfaite.
- Arbre de Décision (CART) :
- Score moyen : 0.976190 avec un écart-type de 0.058321.
- Ce modèle a montré une très légère baisse de performance et une variabilité dans les prédictions, probablement en raison de la structure de l'arbre ou de petites erreurs de classification.
- Naïve Bayes (NB) :
- Score moyen : 0.952381 avec un écart-type de 0.075292.
- Ce modèle montre une précision un peu plus faible, probablement due à l'hypothèse d'indépendance entre les caractéristiques qui n'est pas totalement respectée.
- Support Vector Machines (SVM) :
- Score moyen : 1.000000 (0.000000).
- Performances parfaites, confirmant la capacité des SVM à bien séparer les données.

### 3.5. Analyse des métriques globales :

GIPTIC SII | Application au trieur de M&Ms | Page 26 sur 44
- Accuracy globale : 1.0
- Cela signifie que toutes les instances du jeu de test ont été correctement classées par le modèle final utilisé.

Matrice de confusion :
[2 0 0 0 0 0]
[0 4 0 0 0 0]
[0 0 4 0 0 0]
[0 0 0 3 0 0]
[0 0 0 0 1 0]
[0 0 0 0 0 4]
- Chaque case de la diagonale (par ex., 2 pour la classe 0, 4 pour la classe 1, etc.) montre que toutes les instances de chaque classe ont été correctement prédites.
- L'absence de valeurs hors de la diagonale indique qu'il n'y a eu aucune erreur de classification.
4. Rapport de classification :
| precision | recall | f1-score | support
0 | 1.00 | 1.00 | 1.00 | 2
1 | 1.00 | 1.00 | 1.00 | 4
2 | 1.00 | 1.00 | 1.00 | 4
3 | 1.00 | 1.00 | 1.00 | 3
4 | 1.00 | 1.00 | 1.00 | 1
5 | 1.00 | 1.00 | 1.00 | 4
- Precision, Recall et F1-score :
- Tous les scores sont à 1.00, ce qui reflète une classification parfaite.
- Support : Le nombre d'échantillons par classe (ex. 2 pour la classe 0, 4 pour la classe 1, etc.).

Conclusions :

1. Performance globale :
- Les modèles LR, LDA, KNN et SVM ont montré une précision parfaite (accuracy = 1.0).
- CART et NB ont légèrement moins bien performé, mais restent très proches d'une classification parfaite.
2. Robustesse :
- L'absence d'erreurs dans la matrice de confusion et la cohérence des scores (précision, rappel, F1-score) montrent que les modèles gèrent bien ce jeu de données.
3. Limites potentielles :
- Les performances parfaites pourraient indiquer un surapprentissage si le jeu de données est trop simple ou pas assez diversifié.
- Il serait important de tester ces modèles sur un jeu de données plus varié ou réaliste pour évaluer leur robustesse dans des situations réelles.
4. Choix du modèle :
- Si les ressources sont limitées, LR ou KNN sont simples et performants.
- Pour des applications nécessitant une plus grande adaptabilité, SVM ou CART pourraient être envisagés.

### 3.6 Réalisation du programme en python de tri en fonction des prédictions Tri_Ai

GIPTIC SII | Application au trieur de M&Ms | Page 27 sur 44

from gpiozero import Servo
from time import sleep
from gpiozero.pins.pigpio import PiGPIOFactory import smbus
import time
import csv
import joblib
import pandas as pd

# Configuration des servos avec la bibliothèque GPIOZero et PiGPIOFactory

factory = PiGPIOFactory()

servoh = Servo(18, min_pulse_width=0.56/1000, max_pulse_width=1.85/1000, pin_factory=factory) servob = Servo(17, min_pulse_width=0.52/1000, max_pulse_width=1.8/1000, pin_factory=factory)

# Charger le modèle et le label encoder

modele = joblib.load('LR.pkl')
label_encoder = joblib.load('label_encoder_LR.pkl')

# Définir les positions des servos

servoh_POSITIONS = {
"chargement": 0.56/1000, | # Position de chargement
"mesure": 0.645/1000, | # Position de mesure
"ejection": 1.85/1000 | # Position d'éjection
}

servob_POSITIONS = {
"jaune": -0.95, | # Position pour jaune
"marron": -0.3, | # Position pour marron
"rouge": 0.1, | # Position pour rouge
"orange": -0.7, | # Position pour orange
"vert": 0.6, | # Position pour vert
"bleu": 0.98 | # Position pour bleu
}

# Configuration du bus I2C

bus = smbus.SMBus(1)

# Initialisation du capteur de couleur

def init_sensor():
"""Initialisation du capteur TCS3414."""
bus.write_byte_data(0x39, 0x00 | 0x80, 0x03)

# Lecture des données de couleur

def read_colors():

GIPTIC SII | Application au trieur de M&Ms | Page 28 sur 44

"""Lit les valeurs RGB et de luminosité à partir du capteur TCS3414."""
bus.write_byte_data(0x39, 0x00 | 0x80, 0x03)
bus.write_byte_data(0x39, 0x07 | 0x80, 0x00)
time.sleep(0.5)
data = bus.read_i2c_block_data(0x39, 0x10 | 0x80, 8)
green = data[1] * 256 + data[0]
red = data[3] * 256 + data[2]
blue = data[5] * 256 + data[4]
cData = data[7] * 256 + data[6]

red -= 19
green -= 33
blue -= 16

return cData, red, green, blue

# Déterminer la couleur dominante

def detect_color():
"""Utilise le modèle pour prédire la couleur à partir des valeurs RGB."""
_, red, green, blue = read_colors()
print(f"R: {red}, G: {green}, B: {blue}")

nouvelle_couleur = pd.DataFrame([[red, green, blue]], columns=["Red", "Green", "Blue"])
couleur_encoded = modele.predict(nouvelle_couleur)
couleur = label_encoder.inverse_transform([couleur_encoded[0]])[0]

print(f"Couleur prédite : {couleur}")
return couleur

# Trier les M&M’s

def tri_m_and_ms():
"""Trie les M&M's selon leur couleur prédite.""" while True:
print("Passage en position de chargement...") servoh.min()
sleep(1)

print("Passage en position de mesure...") servoh.mid()
couleur = detect_color()
print(couleur)

if couleur in servob_POSITIONS:
print(f"Tri pour {couleur}...") servob.value = servob_POSITIONS[couleur]

GIPTIC SII | Application au trieur de M&Ms | Page 29 sur 44

sleep(0.5)
servoh.max()
else:
print("Couleur inconnue, ignorer l'objet")

sleep(1)
servob.value = 0

# Programme principal

print("Initialisation...") servoh.mid()
servob.mid()

try:
init_sensor()
tri_m_and_ms()
except KeyboardInterrupt:
print("Arrêt du programme.")

Objectif

Le programme contrôle un système de tri de M&M’s basé sur la détection de couleurs à l’aide d’un Raspberry Pi, un capteur de couleur, et des servomoteurs pour orienter les M&M’s vers différentes positions en fonction de leur couleur prédite.

Structure

1. Initialisation des périphériques :
- Utilise gpiozero pour contrôler les servomoteurs (un pour la position verticale, un pour la rotation horizontale).
- Initialise le bus I2C pour communiquer avec le capteur de couleur TCS3414.
2. Chargement des modèles d’apprentissage automatique :
- Charge un modèle de classification (LogisticRegression) et son encodeur de labels à partir de fichiers .pkl.
3. Définition des positions des servomoteurs :
- Mappe des couleurs prédéfinies à des positions spécifiques des servomoteurs pour orienter les M&M’s.
4. Fonctionnement du capteur :
- init_sensor : Initialise le capteur de couleur.
- read_colors : Lit les données brutes du capteur (RVB, luminance) et applique des corrections.
5. Prédiction des couleurs :
- detect_color : Prédictions basées sur les valeurs RVB mesurées par le capteur, avec un modèle ML et un label encoder pour décoder les prédictions en noms de couleurs.
6. Triage des M&M’s :
- tri_m_and_ms : Cycle continu :
- Positionne le M&M pour mesure.
- Prédit sa couleur.

GIPTIC SII | Application au trieur de M&Ms | Page 30 sur 44
- Oriente le servomoteur correspondant à la couleur prédite.
- Repositionne le système pour le prochain M&M.
7. Gestion des interruptions :
- Permet l’arrêt propre du programme avec Ctrl+C.

Points clés

- Modularité : Chaque étape (lecture capteur, prédiction, tri) est isolée dans une fonction.
- Flexibilité : Les positions des servomoteurs et les couleurs sont configurables.
- Apprentissage automatique : Utilise un modèle préentraîné pour des prédictions plus robustes que des seuils fixes.

3.7 TEST DES MODELS

Régression logistique. LR
# Charger le modèle et le label encoder Exploitationmodele = joblib.load('LR.pkl') label_encoder =

joblib.load('label_encoder_LR.pkl')

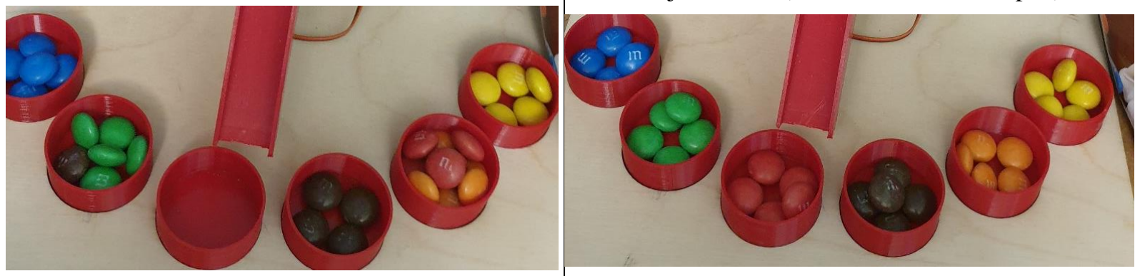
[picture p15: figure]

Confusion rouge et orange un marron dans les verts

Analyse Discriminante Linéaire (LDA) # Charger le modèle et le label encoder modele = joblib.load('DA.pkl') label_encoder =
joblib.load('label_encoder_LDA.pkl')

Tri OK pas d’erreur

k-Nearest Neighbors (KNN) :
modele = joblib.load('KNN.pkl') label_encoder =
joblib.load('label_encoder_KNN.pkl')

Naïve Bayes (NB) :
modele = joblib.load('NB.pkl') label_encoder =
joblib.load('label_encoder_NB.pkl')

GIPTIC SII | Application au trieur de M&Ms | Page 31 sur 44
Tri OK pas d’erreur | Confusion vert, marron et bleu un vert dans les oranges
Arbre de Décision (CART) : modele = joblib.load('KNN.pkl') label_encoder = joblib.load('label_encoder_KNN.pkl') Confusion marron et rouge, un vert dans les oranges | Support Vector Machines (SVM) modele = joblib.load('SVM.pkl') label_encoder = joblib.load('label_encoder_SVM.pkl') Tri OK pas d’erreur

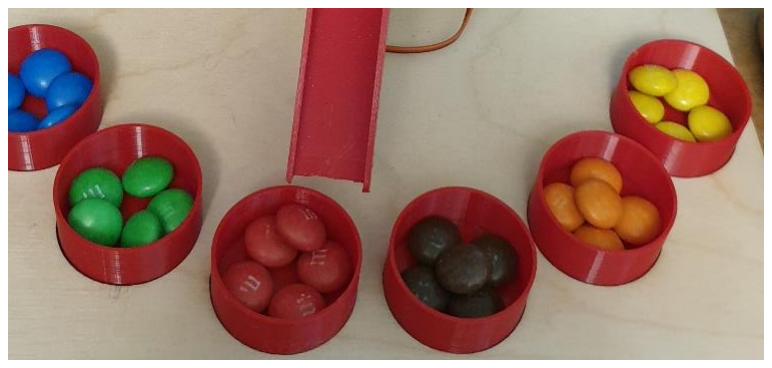
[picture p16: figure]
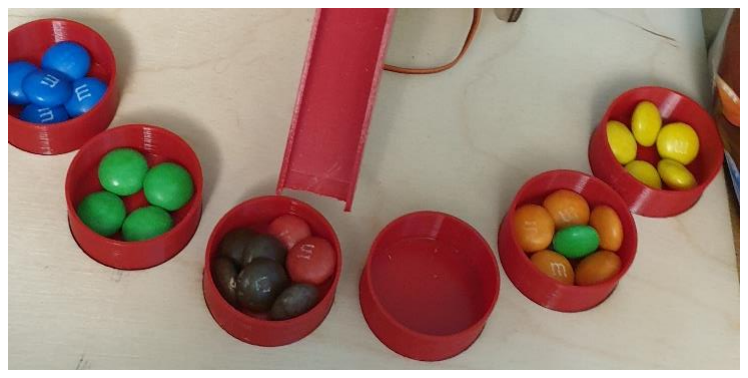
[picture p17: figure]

EN pratique les modèles Analyse Discriminante Linéaire (LDA), k-Nearest Neighbors (KNN) et Support Vector Machines (SVM) : donnent 100% de résultats

Seul le model LR ne correspond pas aux prédictions.

Nous pouvons aussi vérifier la performance avec un dataset différent ou ajouter des variations (lumière, bruit) pour confirmer ces résultats.

## 4.INTRODUCTION AUX RESEAUX DE NEURONES

Principe : Utiliser un réseau de neurones pour classer les couleurs avec davantage de flexibilité.

Etapes principale :
1. Préparation des données
2. Création du model avec Tensoflow/Keras
3. Entrainement du modèle
4. Evaluation du modèle

GIPTIC SII | Application au trieur de M&Ms | Page 32 sur 44
5. Utilisation du model pour prédire des couleurs

## 4.1 Préparation des données

import pandas as pd
import tensorflow as tf
from sklearn.model_selection import train_test_split from sklearn.preprocessing import LabelEncoder from tensorflow.keras.models import Sequential from tensorflow.keras.layers import Dense, Dropout from tensorflow.keras.utils import to_categorical

# Charger les données à partir du fichier CSV

fichier_csv = "couleurs.csv" # Remplacez par le chemin de votre fichier CSV data = pd.read_csv(fichier_csv)

# Préparer les données

X = data[["Red", "Green", "Blue"]].values # Les colonnes RGB y = data["Couleur"].values # La colonne des étiquettes

# Encoder les étiquettes en entiers

label_encoder = LabelEncoder()
y_encoded = label_encoder.fit_transform(y)

# Convertir les étiquettes en format one-hot (nécessaire pour TensorFlow) y_one_hot = to_categorical(y_encoded)

# Diviser les données en ensembles d'entraînement et de test

X_train, X_test, y_train, y_test = train_test_split(X, y_one_hot, test_size=0.2, random_state=42)

## 4.2 Création du model

# Définir le modèle TensorFlow

model = Sequential([
Dense(64, input_dim=3, activation='relu'), # Couche d'entrée Dropout(0.2), # Dropout pour éviter le surapprentissage
Dense(32, activation='relu'), # Couche cachée Dense(y_one_hot.shape[1], activation='softmax') # Couche de sortie ])

# Compiler le modèle

model.compile(optimizer='adam', loss='categorical_crossentropy', metrics=['accuracy'])

## 4.3 Entrainer le model

# Entraîner le modèle

print("Entraînement du modèle...")

GIPTIC SII | Application au trieur de M&Ms | Page 33 sur 44

history = model.fit(X_train, y_train, epochs=50, batch_size=8, validation_data=(X_test, y_test))

# Évaluer le modèle

print("\nÉvaluation sur l'ensemble de test :")
test_loss, test_accuracy = model.evaluate(X_test, y_test) print(f"Précision : {test_accuracy * 100:.2f}%")

# Charger l'historique d'entraînement pour visualisation import matplotlib.pyplot as plt

plt.plot(history.history['accuracy'], label='Train Accuracy') plt.plot(history.history['val_accuracy'], label='Validation Accuracy') plt.xlabel('Epochs')
plt.ylabel('Accuracy')
plt.legend()
plt.show()
# Sauvegarder le modèle entraîné model.save("modele_tensorflow.h5")

print("Modèle sauvegardé sous 'modele_tensorflow.h5'.")

# Sauvegarder l'encodeur des étiquettes

import joblib
joblib.dump(label_encoder, "label_encoder_tensorflow.pkl")
print("Encodeur des étiquettes sauvegardé sous 'label_encoder_tensorflow.pkl'.")

. Deux entrainements avec le même fichier pour 10 mesures par couleur

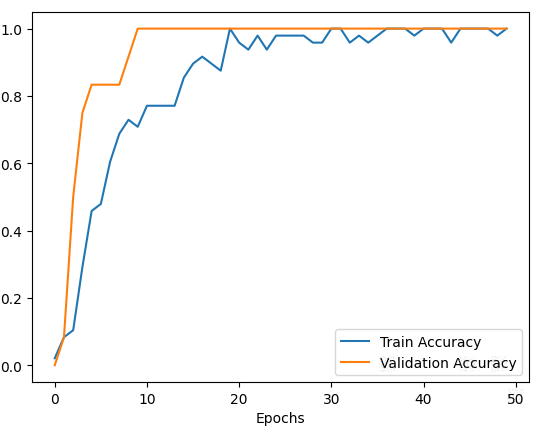
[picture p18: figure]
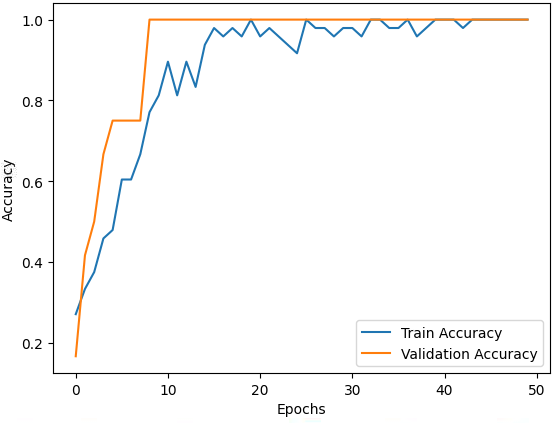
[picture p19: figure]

L’interprétation des courbes **accuracy** et **val_accuracy** dans un graphique représentant l’entraînement et la validation d’un modèle machine learning est essentielle pour évaluer la performance et détecter des problèmes comme le sur apprentissage ou le sous-apprentissage.
Définitions
1. **Accuracy** : Précision sur les données d'entraînement. Elle indique la proportion des prédictions correctes effectuées par le modèle sur les données d'entraînement.
2. **Val_accuracy** : Précision sur les données de validation. Elle mesure la capacité du modèle à généraliser sur des données qu'il n'a pas vues pendant l'entraînement.

GIPTIC SII | Application au trieur de M&Ms | Page 34 sur 44
- | Avec 20 valeurs par couleurs en séquences | Avec 20 valeurs par
| couleurs avec API

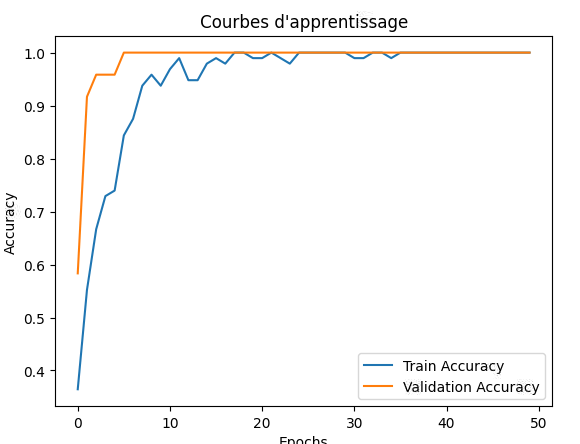
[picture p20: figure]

4.4

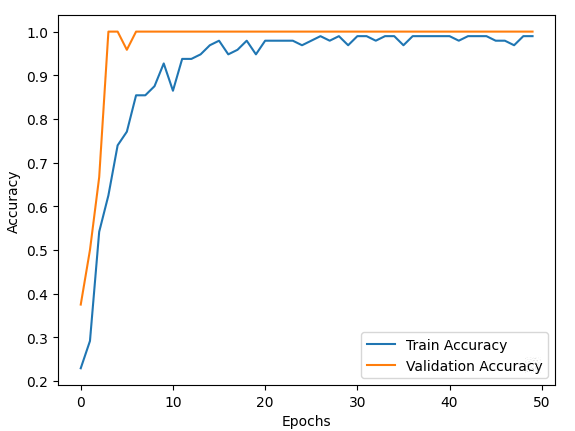
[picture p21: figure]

## Programme de tri avec tensor flow

'''
Pré-requis :
- Lancer la commande `sudo pigpiod` avant d'exécuter ce script.
- Assurez-vous que les bibliothèques nécessaires sont installées :
- tensorflow
- gpiozero
- smbus
- pandas
'''

from gpiozero import Servo
from time import sleep
from gpiozero.pins.pigpio import PiGPIOFactory import smbus
import time
import pandas as pd
import tensorflow as tf
import joblib

# Configuration du Raspberry Pi factory = PiGPIOFactory()

# Initialisation des servomoteurs

servo_horizontal = Servo(18, min_pulse_width=0.56/1000, max_pulse_width=1.85/1000, pin_factory=factory)
servo_vertical = Servo(17, min_pulse_width=0.52/1000, max_pulse_width=1.7/1000, pin_factory=factory)

# Charger le modèle TensorFlow

GIPTIC SII | Application au trieur de M&Ms | Page 35 sur 44

modele = tf.keras.models.load_model('modele_tensorflow.h5')
# Charger l'encodeur de labels

label_encoder = joblib.load('label_encoder_tensorflow.pkl')

# Définir les positions des servomoteurs pour chaque couleur SERVO_POSITIONS = {

"horizontal": {
"chargement": -0.98,
"mesure": 0,
"ejection": 0.98
},
"vertical": {
"jaune": -0.94,
"orange": -0.7,
"marron": -0.3,
"rouge": 0.1,
"vert": 0.55,
"bleu": 0.95
}
}

# Initialisation du bus I2C pour le capteur de couleur bus = smbus.SMBus(1)

# Fonction : Initialiser le capteur de couleur

def init_sensor():
bus.write_byte_data(0x39, 0x00 | 0x80, 0x03) # Activer le capteur
print("Capteur initialisé.")

# Fonction : Lire les données de couleur depuis le capteur

def read_colors():
bus.write_byte_data(0x39, 0x07 | 0x80, 0x00) # Configuration du gain
time.sleep(0.5)
data = bus.read_i2c_block_data(0x39, 0x10 | 0x80, 8) # Lecture des données
red = data[3] * 256 + data[2]
green = data[1] * 256 + data[0]
blue = data[5] * 256 + data[4]

# Calibrage des couleurs pour corriger les déviations red = max(0, red - 19)

green = max(0, green - 33)
blue = max(0, blue - 16)

print(f"Valeurs RGB : R={red}, G={green}, B={blue}") return red, green, blue

# Fonction : Détecter la couleur dominante

def detect_color():
red, green, blue = read_colors()

GIPTIC SII | Application au trieur de M&Ms | Page 36 sur 44

# Préparer les données pour le modèle TensorFlow

nouvelle_couleur = [[red, green, blue]] # Forme attendue : liste de listes
prediction = modele.predict(nouvelle_couleur)
couleur_index = tf.argmax(prediction[0]).numpy() # Index de la classe prédite couleur = label_encoder.inverse_transform([couleur_index])[0] # Décoder l'index print(f"Couleur détectée : {couleur}")
return couleur

# Fonction : Positionner les servomoteurs def position_servo(servo, position): servo.value = position

sleep(0.5)

# Fonction : Trier les M&M's

def tri_m_and_ms():
while True:
print("Déplacement en position de chargement...")
position_servo(servo_horizontal, SERVO_POSITIONS["horizontal"]["chargement"])

print("Déplacement en position de mesure...")
position_servo(servo_horizontal, SERVO_POSITIONS["horizontal"]["mesure"]) couleur = detect_color()

if couleur in SERVO_POSITIONS["vertical"]:
print(f"Tri pour la couleur : {couleur}")
position_servo(servo_vertical, SERVO_POSITIONS["vertical"][couleur]) print("Éjection...")
position_servo(servo_horizontal, SERVO_POSITIONS["horizontal"]["ejection"]) else:
print("Couleur inconnue, objet ignoré.")

sleep(1) # Pause avant la prochaine itération

# Programme principal

if __name__ == "__main__":
try:
print("Initialisation du capteur...") init_sensor()
print("Début du tri...")
tri_m_and_ms()
except KeyboardInterrupt:
print("Programme arrêté par l'utilisateur.") finally:
# Désactiver les servomoteurs servo_horizontal.value = None servo_vertical.value = None print("Servos désactivés.")

GIPTIC SII | Application au trieur de M&Ms | Page 37 sur 44

## 4.5 Résultats obtenu avec TensorFlow sur une base de 120 échantillons

Il reste une confusion entre quelques orange et jaune mais le tri est presque parfait

| Model Séquentiel | Model API

## 5. Entrainement en DeepLearning

Le deep learning est une sous-catégorie de l'intelligence artificielle qui repose sur des réseaux de neurones. Ces réseaux sont particulièrement adaptés pour apprendre des représentations complexes à partir des données brutes, sans nécessiter de règles explicites ou d'étiquetage manuel.

Dans le cadre d’un trieur de couleurs :

- Plutôt que de définir manuellement les seuils RVB ou d'étiqueter des échantillons pour chaque couleur, un réseau de neurones peut apprendre à distinguer les couleurs directement à partir de l’analyse des données brutes capturées par un capteur ou une caméra.
- Ce type de modèle excelle dans des situations où les couleurs se chevauchent ou où les variations de lumière rendent difficile l’utilisation d’approches traditionnelles.

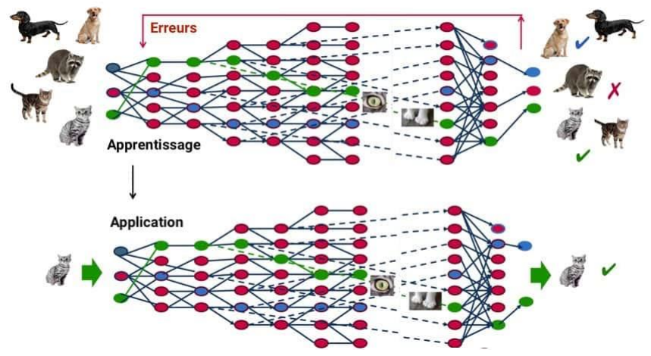
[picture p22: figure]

### 5.1. Chargement et Préparation des Données

- Les données sont chargées depuis un fichier CSV contenant des valeurs RGB. Ces données représentent des couleurs (chaque ligne correspond à une couleur avec des valeurs Red, Green, et Blue).
- Les classes (étiquettes) sont générées automatiquement en utilisant les combinaisons uniques des valeurs RGB. Cela crée une correspondance entre les combinaisons RGB et les indices de classe.

GIPTIC SII | Application au trieur de M&Ms | Page 38 sur 44
- Les étiquettes sont ensuite converties en format one-hot encoding pour être utilisées dans un modèle de classification.

### 5.2. Division des Données

- Les données sont divisées en deux ensembles : un ensemble d'entraînement (80%) et un ensemble de test (20%), pour entraîner et évaluer le modèle.

### 5.3. Construction du Modèle

- Un modèle Sequential est défini avec les couches suivantes :
- Dense(64, relu) : Une couche dense (fully connected) avec 64 neurones et activation ReLU.
- Dropout(0.2) : Une régularisation Dropout pour réduire le surapprentissage.
- Dense(32, relu) : Une deuxième couche dense avec 32 neurones.
- Dense(output, softmax) : Une couche de sortie avec un nombre de neurones correspondant au nombre de classes (softmax pour une classification multiclasse).

### 5.4. Compilation et Entraînement

- Le modèle est compilé avec :
- L'optimiseur Adam.
- Une fonction de perte categorical_crossentropy (adaptée au problème de classification multiclasse).
- Une métrique d'évaluation : accuracy.
- Le modèle est entraîné sur 50 époques avec une taille de batch de 8.

### 5.5. Évaluation et Visualisation

- Le modèle est évalué sur l'ensemble de test pour mesurer sa précision.
- Les performances d'entraînement et de validation (accuracy) sont tracées pour analyser la convergence du modèle.

### 5.6. Sauvegarde des Résultats

- Le modèle entraîné est sauvegardé sous le format .h5.
- L'encodeur des étiquettes (association entre les classes et les combinaisons RGB) est également sauvegardé pour une utilisation future.

### 5.7 Objectif du Programme

Le but est d'entraîner un modèle de classification capable d'identifier des couleurs (ou classes) à partir de leurs combinaisons RGB. Ce programme pourrait être utilisé dans des applications comme la reconnaissance de couleurs ou des systèmes basés sur des palettes colorimétriques.

import pandas as pd
import tensorflow as tf
from sklearn.model_selection import train_test_split from tensorflow.keras.models import Sequential from tensorflow.keras.layers import Dense, Dropout from tensorflow.keras.utils import to_categorical import matplotlib.pyplot as plt
import joblib
import numpy as np

# Charger les données depuis le fichier CSV

fichier_csv = "couleurs_deep.csv" # Remplacez par le chemin de votre fichier CSV data = pd.read_csv(fichier_csv)

# Les données ne contiennent pas de colonne de labels explicites

# On suppose que chaque combinaison RGB correspond à une classe unique # Charger les données sans la colonne des labels explicites

X = data.values # Les colonnes RGB

GIPTIC SII | Application au trieur de M&Ms | Page 39 sur 44

# S'assurer que les données sont de type float

X = X.astype(float)

# Vérifier et gérer les valeurs manquantes if pd.isnull(X).any():

X = pd.DataFrame(X).fillna(0).values

# Générer des étiquettes basées sur des combinaisons uniques de RGB y = pd.factorize([tuple(rgb) for rgb in X])[0]

# Convertir les étiquettes en format one-hot

y_one_hot = to_categorical(y)

# Diviser les données en ensembles d'entraînement et de test

X_train, X_test, y_train, y_test = train_test_split(X, y_one_hot, test_size=0.2, random_state=42)

# Définir le modèle TensorFlow

model = Sequential([
Dense(64, input_dim=3, activation='relu'), # Couche d'entrée avec 3 neurones pour RGB Dropout(0.2), # Dropout pour éviter le surapprentissage
Dense(32, activation='relu'), # Couche cachée
Dense(y_one_hot.shape[1], activation='softmax') # Couche de sortie
])

# Compiler le modèle

model.compile(optimizer='adam', loss='categorical_crossentropy', metrics=['accuracy'])

# Entraîner le modèle

print("Entraînement du modèle...")
history = model.fit(X_train, y_train, epochs=50, batch_size=8, validation_data=(X_test, y_test)) # Convertir les étiquettes one-hot en indices
y_test_indices = np.argmax(y_test, axis=1)# Convertir les étiquettes one-hot en indices

# Afficher les indices des classes

print(f"Indices des classes dans les données d'entraînement : {sorted(set(y_test_indices))}")

# Évaluer le modèle

print("\nÉvaluation sur l'ensemble de test :")
test_loss, test_accuracy = model.evaluate(X_test, y_test) print(f"Précision : {test_accuracy * 100:.2f}%")

# Visualisation de l'historique d'entraînement plt.plot(history.history['accuracy'], label='Train Accuracy') plt.plot(history.history['val_accuracy'], label='Validation Accuracy') plt.xlabel('Epochs')

plt.ylabel('Accuracy')
plt.legend()
plt.show()

GIPTIC SII | Application au trieur de M&Ms | Page 40 sur 44

# Sauvegarder le modèle entraîné

model.save("modele_tensorflow DeepL.h5")
print("Modèle sauvegardé sous 'modele_tensorflow DeepL.h5'.")

# Sauvegarder l'encodeur des étiquettes

joblib.dump(pd.factorize([tuple(rgb) for rgb in X])[1], "label_encoder_tensorflow DeepL.pkl") print("Encodeur des étiquettes sauvegardé sous 'label_encoder_tensorflow DeepL.pkl'.")

5.8 Resultat

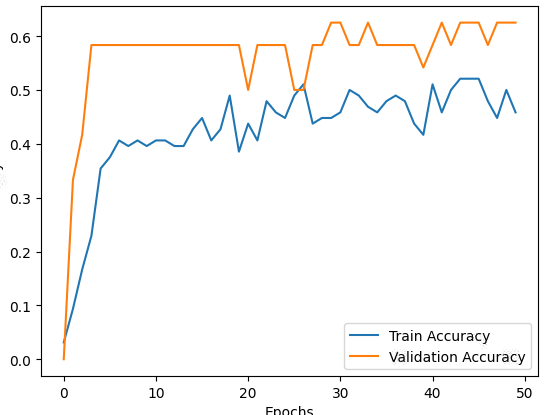
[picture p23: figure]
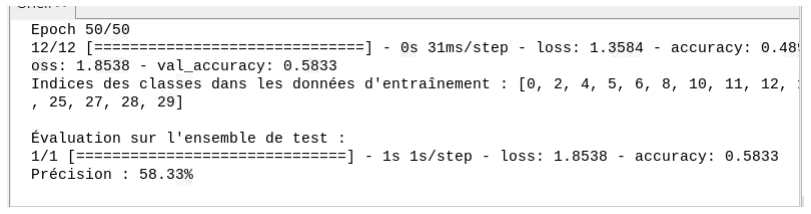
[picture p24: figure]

## 6. Programme de tri avec le model tensorflow

Ce programme utilise un Raspberry Pi, des servomoteurs, un capteur de couleur, et un modèle TensorFlow pour trier des M&M's en fonction de leurs couleurs détectées

### 6.1. Initialisation et configuration

- Raspberry Pi et servomoteurs :
- Deux servomoteurs sont initialisés avec des largeurs d’impulsion spécifiques pour leur fonctionnement :
- servo_horizontal : contrôle les mouvements horizontaux (chargement, mesure, éjection).
- servo_vertical : contrôle les mouvements verticaux (position pour chaque couleur détectée).
- Modèle TensorFlow :
- Le modèle préentraîné (modele_tensorflow DeepL.h5) est chargé pour identifier la couleur (classe) d’un M&M en fonction de ses valeurs RGB.
- Table des positions (SERVO_POSITIONS) :
- Définit les positions des servomoteurs pour chaque étape (chargement, mesure, éjection) et pour chaque couleur (index de classe).

### 6.2. Fonctionnement

1. Initialisation du capteur de couleur :
- Le capteur I2C est configuré pour détecter les couleurs.
- Les données brutes (RGB) sont lues et calibrées pour corriger les variations matérielles.

GIPTIC SII | Application au trieur de M&Ms | Page 41 sur 44
2. Détection de la couleur :
- Les valeurs RGB sont envoyées au modèle TensorFlow pour obtenir une prédiction.
- La prédiction renvoie un index de classe représentant la couleur détectée.
3. Positionnement des servomoteurs :
- Selon l’index de la couleur détectée :
- servo_horizontal positionne le M&M en mesure, puis en éjection.
- servo_vertical déplace le M&M à la position correspondant à sa couleur.
4. Triage des M&M's :
- Le programme suit une boucle infinie :
- Le M&M est chargé en position de mesure.
- Sa couleur est détectée.
- Il est déplacé à la position correspondant à sa couleur ou à une position par défaut si la
| couleur est inconnue.

### 6.3. Points clés

- Capteur de couleur :
- Lit les valeurs RGB via I2C et applique une correction (calibrage).
- Modèle TensorFlow :
- Classe les couleurs détectées en utilisant un modèle préentraîné.
- Servomoteurs :
- Contrôlent les mouvements pour trier les M&M's selon leurs couleurs.
- Sécurité :
- Une interruption (KeyboardInterrupt) désactive les servomoteurs pour éviter tout dommage.

Résumé global

Le programme automatise le tri de M&M's par couleur en utilisant un capteur de couleur pour détecter leurs valeurs RGB, un modèle TensorFlow pour classer les couleurs, et des servomoteurs pour les déplacer vers des emplacements spécifiques.

from gpiozero import Servo
from time import sleep
from gpiozero.pins.pigpio import PiGPIOFactory import smbus
import time
import tensorflow as tf

# Configuration du Raspberry Pi factory = PiGPIOFactory()

# Initialisation des servomoteurs

servo_horizontal = Servo(18, min_pulse_width=0.56/1000, max_pulse_width=1.85/1000, pin_factory=factory)
servo_vertical = Servo(17, min_pulse_width=0.52/1000, max_pulse_width=1.7/1000, pin_factory=factory)

# Charger le modèle TensorFlow

GIPTIC SII | Application au trieur de M&Ms | Page 42 sur 44

modele = tf.keras.models.load_model('modele_tensorflow DeepL.h5')

# Définir les positions des servomoteurs pour chaque index de couleur SERVO_POSITIONS = {

"horizontal": {
"chargement": -0.98,
"mesure": 0,
"ejection": 0.98
},
"vertical": {
25: -0.94, # Jaune
27: -0.7, # Orange
15: -0.3, # Marron
9: 0.1, # Rouge
28: 0.1, # Rouge
12: 0.55, # Vert
13: 0.55, # Vert
4: 0.95 # Bleu
}
}

# Initialisation du bus I2C pour le capteur de couleur bus = smbus.SMBus(1)

def afficher_indices_classes():
print("Correspondance des indices et des positions des couleurs dans SERVO_POSITIONS :") for index, position in SERVO_POSITIONS["vertical"].items():
print(f"Index : {index}, Position servo : {position}")

# Fonction : Initialiser le capteur de couleur

def init_sensor():
bus.write_byte_data(0x39, 0x00 | 0x80, 0x03) # Activer le capteur
print("Capteur initialisé.")

# Fonction : Lire les données de couleur depuis le capteur

def read_colors():
bus.write_byte_data(0x39, 0x07 | 0x80, 0x00) # Configuration du gain
time.sleep(0.5)
data = bus.read_i2c_block_data(0x39, 0x10 | 0x80, 8) # Lecture des données
red = data[3] * 256 + data[2]
green = data[1] * 256 + data[0]
blue = data[5] * 256 + data[4]

# Calibrage des couleurs pour corriger les déviations red = max(0, red - 19)

green = max(0, green - 33)
blue = max(0, blue - 16)

print(f"Valeurs RGB : R={red}, G={green}, B={blue}")

GIPTIC SII | Application au trieur de M&Ms | Page 43 sur 44

return red, green, blue

# Fonction : Détecter l'index de la couleur

def detect_color_index():
red, green, blue = read_colors()
# Préparer les données pour le modèle TensorFlow

nouvelle_couleur = [[red, green, blue]] # Forme attendue : liste de listes

# Faire la prédiction

prediction = modele.predict(nouvelle_couleur)
print(f"Probabilités de la prédiction : {prediction[0]}")
couleur_index = tf.argmax(prediction[0]).numpy() # Index de la classe prédite print(f"Index de la couleur détectée : {couleur_index}")
return couleur_index

# Fonction : Positionner les servomoteurs

def position_servo(servo, position): servo.value = position
sleep(0.5)

# Fonction : Trier les M&M's

def tri_m_and_ms():
while True:
print("Déplacement en position de chargement...")
position_servo(servo_horizontal, SERVO_POSITIONS["horizontal"]["chargement"])

print("Déplacement en position de mesure...")
position_servo(servo_horizontal, SERVO_POSITIONS["horizontal"]["mesure"]) couleur_index = detect_color_index()

if couleur_index in SERVO_POSITIONS["vertical"]:
print(f"Tri pour la couleur d'index : {couleur_index}") position_servo(servo_vertical, SERVO_POSITIONS["vertical"][couleur_index]) print("Éjection...")
position_servo(servo_horizontal, SERVO_POSITIONS["horizontal"]["ejection"]) else:
print(f"Couleur inconnue (index {couleur_index}), éjection à une position par défaut.") position_servo(servo_vertical, 0) # Position par défaut ou d'échec

sleep(1) # Pause avant la prochaine itération

# Programme principal

if __name__ == "__main__":
try:
print("Initialisation du capteur...") init_sensor()
afficher_indices_classes()
sleep(10) # Pause avant la prochaine itération

GIPTIC SII | Application au trieur de M&Ms | Page 44 sur 44

print("Début du tri...")
tri_m_and_ms()
except KeyboardInterrupt:
print("Programme arrêté par l'utilisateur.") finally:
# Désactiver les servomoteurs servo_horizontal.value = None servo_vertical.value = None

print("Servos désactivés.")

Resultat obtenu il y a trois M&Ms bleu avec les verts et deux rouges avec les oranges

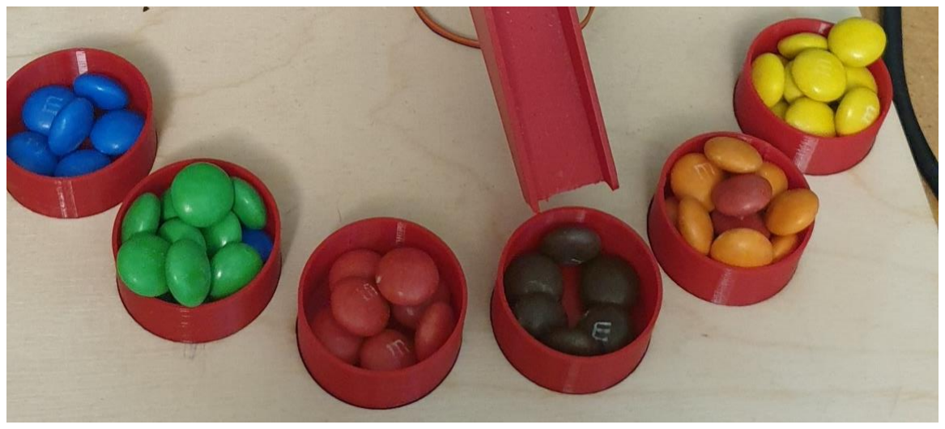
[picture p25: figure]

# MERCI DE VOTRE ATTENTION

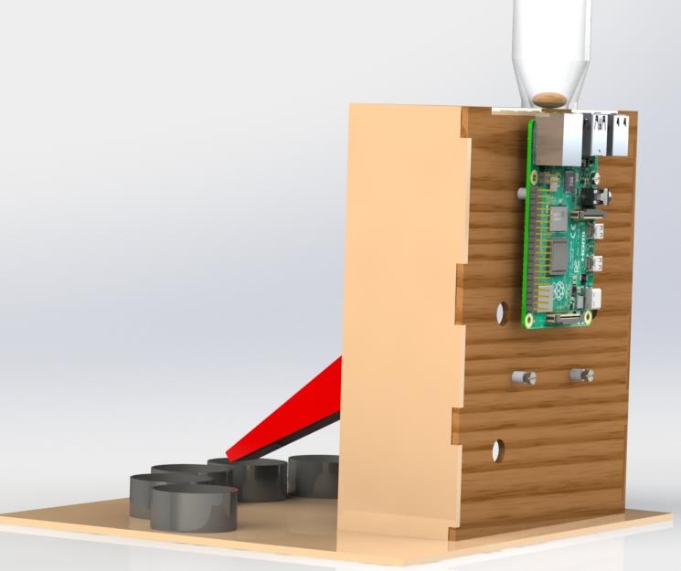
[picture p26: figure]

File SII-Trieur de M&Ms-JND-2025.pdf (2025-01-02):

Mercredi 12 février 2025

Journée du Numérique
L’IA en pratique

Utilisation de l'IA dans des
applications pratiques

SCAI sur le campus de Jussieu


Muracciole Vincent & Lasne Fabrice | 2 | 12/02/2025

# SOMMAIRE

# - Objectifs de la présentation :

## Pourquoi l’IA en classe de SSI ?

# - Présentation du projet de trieur de M&Ms

## Montrer l'intérêt de l'IA dans des projets pédagogiques pratiques

# - Utilisation de l'IA pour améliorer le système

## Approche avec un modèle d’IA classique

# - Introduction au Deep Learning

## Approche avec un réseau de neurones convolutif (CNN) :

# - Intégration et applications pédagogiques

## Intégration du système complet :

# - Conclusion et échanges

3

•Montrer l'intérêt de l'IA dans des projets pédagogiques pratiques.

# •Comparer une solution classique avec des approches utilisant l'IA et le deep

learning.

•Illustrer l'application concrète avec un trieur de couleurs pour des M&M's.

# Pourquoi l’IA en classe de SSI ?

•Relever les compétences pour le futur (industrie, recherche, quotidien).

# •Développement de compétences transversales

(mathématiques, algorithmique, analyse).

•Possibilité de rendre les projets plus attractifs et engageants.


Muracciole Vincent & Lasne Fabrice | 12/02/2025

# Objectifs de la présentation :


4 Muracciole Vincent & Lasne Fabrice | 12/02/2025

•Fonctionnement d’un trieur de couleurs pour des M&M's.

•Utilisation d’un Raspberry Pi comme plateforme de développement.

•Acquisition des données : capteur RGB.

## Solution classique :

- Mesure des valeurs de couleur (RVB ou HSL).

## - Comparaison par seuils ou calcul d’écart entre les valeurs

mesurées et des valeurs de référence pour chaque couleur.

## - Limites de cette approche :

- Sensibilité aux variations de lumière.
- Complexité si les couleurs se chevauchent dans l’espace RVB.

# Description du système :

# Détection de lumière réfléchie :


5 Muracciole Vincent & Lasne Fabrice | 12/02/2025

## - Éclairage intégré :

Le TCS34725 possède une LED blanche intégrée pour fournir un éclairage constant, améliorant la précision des mesures indépendamment des conditions lumineuses ambiantes.


6 Muracciole Vincent & Lasne Fabrice | 12/02/2025

# Approche classique : Analyse des écarts de valeurs mesurées

### 1. Servo 1 : avec trois positions :

- Position 1 : Chargement.
- Position 2 : Mesure.
- Position 3 : Éjection.

### 2. Servo 2 :

- 6 positions pour trier les M&M’s par couleur :
marron, vert, orange,
jaune, rouge, bleu.

### 3. Capteur TCS34725

### 1. Initialisation :

- Le capteur et les servos sont initialisés dans les positions par défaut.

### 2. Collecte des Échantillons :

- Pour chaque couleur dans la liste COULEUR, le programme lit les données RGB pour 10 pastilles (ou une valeur ajustable dans

num_samples).
- Entre chaque lecture, le servo horizontal (servoh) est déplacé pour la position de mesure de déchargement et de chargement.

### 3. Enregistrement des Données :

- Une fois toutes les pastilles mesurées, les données sont enregistrées dans un fichier CSV avec des colonnes pour la couleur et les valeurs RGB.

Red,Green,Blue,Couleur
0.0,2.0,5.0,bleu
0.0,2.0,5.0,bleu
-1.0,0.0,4.0,bleu
0.0,0.0,4.0,bleu
0.0,0.0,4.0,bleu
0.0,0.0,4.0,bleu
0.0,1.0,4.0,bleu
0.0,1.0,5.0,bleu
0.0,1.0,5.0,bleu
0.0,0.0,4.0,bleu
6.0,-1.0,0.0,rouge
6.0,-1.0,0.0,rouge
6.0,-1.0,0.0,rouge
6.0,-1.0,0.0,rouge
5.0,-1.0,0.0,rouge
6.0,-1.0,0.0,rouge
6.0,-1.0,0.0,rouge
6.0,-1.0,0.0,rouge
6.0,0.0,1.0,rouge
6.0,0.0,0.0,rouge

## Maquette de détection des

couleurs | Création d’un fichier csv
| avec lecture des couleurs

## Principe de création du fichier csv


7 Muracciole Vincent & Lasne Fabrice | 12/02/2025

# Détermination des écarts de couleurs :

import csv
# Fonction pour calculer les plages de variation des couleurs def calculate_color_ranges(file_path):

color_data = {}
# Lecture du fichier CSV

with open(file_path, 'r', encoding='utf-8') as csvfile: reader = csv.reader(csvfile)
next(reader) # Ignorer les en-têtes
for row in reader:
r, g, b, color = float(row[0]), float(row[1]), float(row[2]), row[3] if color not in color_data:
color_data[color] = {"R": [], "G": [], "B": []} color_data[color]["R"].append(r) color_data[color]["G"].append(g) color_data[color]["B"].append(b)
# Calcul des plages pour chaque couleur color_ranges = {}

for color, channels in color_data.items(): color_ranges[color] = {
"R": (min(channels["R"]), max(channels["R"])), "G": (min(channels["G"]), max(channels["G"])), "B": (min(channels["B"]), max(channels["B"])) }
return color_ranges
# Fonction principale

def main():
file_path = "couleurs_echantillons.csv" # Remplacez par le chemin de votre fichier CSV
color_ranges = calculate_color_ranges(file_path)

print("Plages de variation des couleurs :")
for color, ranges in color_ranges.items(): print(f"{color.capitalize()} :")
print(f" R (Rouge) : {ranges['R']}") print(f" G (Vert) : {ranges['G']}") print(f" B (Bleu) : {ranges['B']}") # Exécution du script
if __name__ == "__main__":
main()
- Lecture des données CSV :

### Le fichier CSV est lu ligne par ligne, et les valeurs RGB associées à chaque couleur sont

stockées dans un dictionnaire.
- Calcul des plages de variation :

### Pour chaque couleur, les valeurs minimales et

maximales de R, G et B sont déterminées.
- Affichage des résultats :

### Les plages de variation pour chaque couleur

sont imprimées de manière lisible.

| R | G | B
min max min max min max
Color
bleu | 0.0 0.0 | 1.0 2.0 | 4.0 5.0
jaune | 10.0 12.0 10.0 13.0 2.0 3.0
marron | 0.0 1.0 | -1.0 -1.0 | 0.0 1.0
orange | 8.0 10.0 | 3.0 4.0 | 1.0 1.0
rouge | 6.0 7.0 | 0.0 1.0 | 0.0 1.0
vert | 1.0 2.0 | 4.0 5.0 | 2.0 2.0

COLOR_RANGES = {
"bleu": [(0.0, 0.0), (1.0, 2.0), (4.0, 5.0)], "rouge": [(6.0, 7.0), (0.0, 1.0), (1.0, 1.0)], "vert": [(2.0, 2.0), (5.0, 6.0), (2.0, 2.0)], "marron": [(0.0, 1.0), (-1.0, -1.0), (0.0, 1.0)], "jaune": [(10.0, 12.0), (10.0, 13.0), (2.0, 3.0)], "orange": [(9.0, 11.0), (4.0, 5.0), (1.0, 2.0)], }

### Ecart min et max pour les 6 couleurs

### Utilisation dans le programme pour les 6 couleurs

Programme | Fonctionnement


8 Muracciole Vincent & Lasne Fabrice | 12/02/2025

# Tri par fourchette de couleurs:

### 1. Servo 1 :

- Change entre 3 positions (chargement, mesure, éjection) pour gérer le flux des M&M’s.
- Les angles pour chaque position sont définis dans max mid et min.

### 2. Détection des couleurs :

- Les couleurs sont détectées en comparant les valeurs de rouge, vert et bleu.
- Des seuils sont définis pour certaines couleurs complexes comme jaune, orange ou marron.

### 3. Servo 2 :

- Positionné selon la couleur détectée : marron, vert, orange, jaune, rouge, ou bleu.
- Les angles pour chaque couleur sont

définis dans SERVO2_POSITIONS.

### 1. Tri :

- Le premier servo gère le déplacement des M&M’s entre les étapes.
- Le second servo place les M&M’s dans le compartiment correspondant.

# Déterminer la couleur dominante def detect_color():

_, r, g, b = read_colors()
print(f"R: {r}, G: {g}, B: {b}")
tolerance = 1
for color, (r_range, g_range, b_range) in COLOR_RANGES.items(): if (
(r_range[0] - tolerance) <= r <= (r_range[1] + tolerance) and (g_range[0] - tolerance) <= g <= (g_range[1] + tolerance) and (b_range[0] - tolerance) <= b <= (b_range[1] + tolerance)
):
return color
return "inconnu"

servob_POSITIONS = {
"marron": -0.3, # Position pour marron "vert": 0.6, # Position pour vert "orange": -0.95, # Position pour orange "jaune": -0.7, # Position pour jaune
"rouge": 0.1, | # Position pour rouge
"bleu": 0.9 | # Position pour bleu
}

COLOR_RANGES = {
"bleu": [(0.0, 0.0), (1.0, 2.0), (4.0, 5.0)], "rouge": [(6.0, 7.0), (0.0, 1.0), (1.0, 1.0)], "vert": [(2.0, 2.0), (5.0, 6.0), (2.0, 2.0)], "marron": [(0.0, 1.0), (-1.0, -1.0), (0.0, 1.0)], "jaune": [(10.0, 12.0), (10.0, 13.0), (2.0, 3.0)], "orange": [(9.0, 11.0), (4.0, 5.0), (1.0, 2.0)],

}

## Gestion de la position et des écarts

## Gestion du tri avec une tolérance de 1

## TRI OK avec une tolérance de 1 mais des couleurs sont mesurées plusieurs fois

## Tolérance de 2 pas de pb de lectures mais des couleurs sont mal reconnues

Fonctionnement | Programme


9 Muracciole Vincent & Lasne Fabrice | 12/02/2025

# Introduction au modèles d’IA classiques

- Principe :
Remplacer la logique conditionnelle par un modèle d'IA entraîné pour classer les couleurs.
- Modèles abordés :
- Régression logistique. LR
- Forêt aléatoire.
- k-Nearest Neighbors (k-NN).
- LDA
- Naïve Bayes
- SVM

Quatre étapes à réaliser :

### 1. Collecte de données : Créer un dataset en mesurant

des valeurs RVB et en annotant manuellement les couleurs.

### 2. Entraînement des modèles : Utiliser une bibliothèque

comme scikit-learn pour entraîner un modèle sur les données collectées.

### 3. Évaluation : Comparer les performances des différents

modèles sur des M&M's non vus pendant l'entraînement.

### 4. Implémentation : Intégrer le modèle choisi dans le

programme pour trier les M&M's en temps réel.

### Résumé : Quand utiliser quel modèle ?

Modèle | Complexité | Données linéaires | Données non
linéaires | Interprétabilité Rapidité
Régression logistique Faible | Oui | Non | Élevée | Rapide
LDA | Moyenne | Oui | Non | Moyenne | Moyenne
k-NN | Faible | Oui | Oui | Moyenne | Lent
Arbre de décision | Moyenne | Oui | Oui | Élevée | Moyenne
Naïve Bayes | Faible | Oui | Non | Moyenne | Rapide
SVM | Élevée | Oui | Oui (avec noyaux) Faible | Lent

# Machine Learning


10 Muracciole Vincent & Lasne Fabrice | 12/02/2025

# Entrainement du modèle

### 1. Chargement des données : Ajout de

gestion d'erreur pour s'assurer que le fichier CSV existe avant de continuer.

### 2. Exploration des données : Ajout d'une

matrice de dispersion pour visualiser les relations entre les caractéristiques.

### 3. Préparation des données : Utilisation

explicite de iloc pour séparer les caractéristiques et les labels.

### 4. Comparaison des modèles : Résultats

affichés avec moyenne et écart type. Les graphiques de comparaison sont ajoutés Entraînement et sauvegarde : Fonction utilitaire pour éviter la duplication de code, avec des évaluations détaillées pour chaque modèle.

import pandas as pd
from pandas.plotting import scatter_matrix
from matplotlib import pyplot as plt
from sklearn.model_selection import train_test_split, cross_val_score, StratifiedKFold
from sklearn.linear_model import LogisticRegression from sklearn.tree import DecisionTreeClassifier from sklearn.neighbors import KNeighborsClassifier from sklearn.discriminant_analysis import LinearDiscriminantAnalysis
from sklearn.naive_bayes import GaussianNB
from sklearn.svm import SVC
from sklearn.metrics import classification_report, confusion_matrix, accuracy_score
from sklearn.preprocessing import LabelEncoder
import joblib
Fonctionnement | Utilisation des bibliothèques Sklearn

# Matrice de dispersion des variables scatter_matrix(dataset)

plt.title("Scatter Matrix of Dataset") plt.show()

# === 2. Préparation des données ===

# Séparation des caractéristiques (RVB) et des labels (classe des couleurs)

X = dataset.iloc[:, :3].values | # Colonnes RVB
Y = dataset.iloc[:, 3].values | # Classe de couleur

# Encodage des labels (classes des couleurs) label_encoder = LabelEncoder()

Y_encoded = label_encoder.fit_transform(Y)

# Séparation des données en ensembles d'entraînement et de validation

X_train, X_validation, Y_train, Y_validation = train_test_split(
X, Y_encoded, test_size=0.30, random_state=1 )

# === 3. Définition et évaluation des modèles ===

# Liste des modèles à tester

models = [
('LR', LogisticRegression(solver='liblinear', multi_class='ovr')),
('LDA', LinearDiscriminantAnalysis()), ('KNN', KNeighborsClassifier()),
('CART', DecisionTreeClassifier()), ('NB', GaussianNB()),
('SVM', SVC(gamma='auto'))
]


11 Muracciole Vincent & Lasne Fabrice | 12/02/2025

# Exploitation des résultats

Régression logistique. LR Exploitationmodele = joblib.load('LR.pkl') label_encoder = joblib.load('label_encoder_LR.pkl') Confusion rouge et orange un marron dans les verts | Analyse Discriminante Linéaire (LDA) modele = joblib.load('DA.pkl') label_encoder = joblib.load('label_encoder_LDA.pkl') Tri OK pas d’erreur
k-Nearest Neighbors (KNN) : modele = joblib.load('KNN.pkl') label_encoder = joblib.load('label_encoder_KNN.pkl') Tri OK pas d’erreur | Naïve Bayes (NB) : modele = joblib.load('NB.pkl') label_encoder = joblib.load('label_encoder_NB.pkl') Confusion vert, marron et bleu un vert dans les oranges
Arbre de Décision (CART) : modele = joblib.load('KNN.pkl') label_encoder = joblib.load('label_encoder_KNN.pkl') Confusion marron et rouge, un vert dans les oranges | Support Vector Machines (SVM) modele = joblib.load('SVM.pkl') label_encoder = joblib.load('label_encoder_SVM.pkl') Tri OK pas d’erreur


12 Muracciole Vincent & Lasne Fabrice | 12/02/2025

# Introduction aux réseaux de neurones

Un réseau de neurones est un modèle d'intelligence artificielle inspiré du fonctionnement du cerveau humain, conçu pour résoudre des problèmes complexes en apprenant des données.
1.Structure :
•Il est composé de couches de neurones :
•Une couche d’entrée (reçoit les données brutes).
•Une ou plusieurs couches cachées (effectuent des transformations intermédiaires).
•Une couche de sortie (fournit le résultat ou la prédiction). •Chaque neurone dans une couche est connecté à ceux de la couche suivante.

2.Traitement des données :
•Chaque connexion entre neurones est pondérée par un poids, qui détermine l'importance d'une entrée spécifique.
•Chaque neurone applique une fonction d’activation pour introduire des non-linéarités et permettre au réseau de modéliser des relations complexes.

3.Apprentissage :
•Lors de l’entraînement, le réseau ajuste les poids en fonction de l’erreur entre sa prédiction et le résultat attendu.
•Un algorithme d’optimisation (comme la rétro propagation et la descente de gradient) met à jour les poids pour réduire cette erreur.

4.Objectif :
•À mesure que le réseau apprend, il devient capable de généraliser les relations dans les données pour faire des prédictions sur de nouvelles données.

En résumé, un réseau de neurones est un modèle d’apprentissage automatique qui affine ses connexions internes pour identifier des patterns et fournir des prédictions ou classifications à partir de données d’entrée.

import tensorflow as tf

# Modèle simple

model = tf.keras.Sequential([
tf.keras.layers.Dense(128, activation='relu', input_shape=(784,)), tf.keras.layers.Dropout(0.2),
tf.keras.layers.Dense(10, activation='softmax')
])

# Compilation

model.compile(
optimizer=tf.keras.optimizers.Adam(learning_rate=0.001), loss='sparse_categorical_crossentropy', metrics=['accuracy']
)

# Entraînement

history = model.fit(x_train, y_train, epochs=10, batch_size=32, validation_data=(x_val, y_val))

# Utilisation avec tensorflow


13 Muracciole Vincent & Lasne Fabrice | 12/02/2025

Principe : Utiliser un réseau de neurones pour classer les couleurs avec davantage de flexibilité.
Etapes principale :
1. Préparation des données
2. Création du model avec Tensoflow/Keras
3. Entrainement du modèle
4. Evaluation du modèle
5. Utilisation du model pour prédire des couleurs

# Définir le modèle TensorFlow

model = Sequential([
Dense(64, input_dim=3, activation='relu'), # Couche d'entrée
Dropout(0.2), # Dropout pour éviter le surapprentissage Dense(32, activation='relu'), # Couche cachée Dense(y_one_hot.shape[1], activation='softmax') # Couche de sortie
])

# Compiler le modèle

model.compile(optimizer='adam', loss='categorical_crossentropy', metrics=['accuracy'])

# Définir le modèle en utilisant l'API fonctionnelle

inputs = Input(shape=(3,), name="Input_Layer") # Couche d'entrée
x = Dense(64, activation='relu', name="Dense_1")(inputs) # Première couche dense
x = Dropout(0.2, name="Dropout_1")(x) # Dropout pour régularisation
x = Dense(32, activation='relu', name="Dense_2")(x) # Deuxième couche dense
outputs = Dense(y_one_hot.shape[1], activation='softmax', name="Output_Layer")(x) # Couche de sortie

# Création du modèle

model = Model(inputs=inputs, outputs=outputs)
Model séquentiel | Model API


14 Muracciole Vincent & Lasne Fabrice | 12/02/2025

# Introduction au Deep learning

## Le deep learning est une sous-catégorie de l'intelligence artificielle qui repose sur des réseaux de neurones. Ces réseaux sont particulièrement adaptés pour apprendre des représentations complexes à partir des données brutes, sans nécessiter de règles explicites

ou d'étiquetage manuel.

## Dans le cas d’un trieur de couleurs : •Données d’entrée : Les valeurs brutes mesurées par un

capteur RGB (ou les pixels d’une image capturée).

## •Traitement :

## - Le réseau de neurones apprend à identifier des motifs dans les données (par exemple, des

regroupements naturels des couleurs).

## - Les couches internes du réseau découvrent des représentations implicites des caractéristiques de

chaque couleur.

## •Décision : Le réseau décide à quelle catégorie (couleur) appartient l’échantillon, sans qu’il soit nécessaire de fournir

des règles explicites.

# Deep Learning avec tensor flow

## Chargement et Préparation des Données


15 Muracciole Vincent & Lasne Fabrice | 12/02/2025

## Indices des classes dans les données

d'entraînement : [0, 2, 4, 5, 6, 8, 10, 11, 12, 15, 17, 24, 25, 27, 28, 29]

# Diviser les données en ensembles d'entraînement et de test

X_train, X_test, y_train, y_test = train_test_split(X, y_one_hot, test_size=0.2, random_state=42)

# Définir le modèle TensorFlow model = Sequential([

Dense(64, input_dim=3,
activation='relu'), # Couche d'entrée avec 3 neurones pour RGB
Dropout(0.2), # Dropout pour éviter le surapprentissage
Dense(32, activation='relu'), # Couche cachée
Dense(y_one_hot.shape[1],
activation='softmax') # Couche de sortie ])

# Compiler le modèle

model.compile(optimizer='adam', loss='categorical_crossentropy', metrics=['accuracy'])

## "vertical": { 25: -0.94, # Jaune 27: -0.7, # Orange 15: -0.3, # Marron 9: 0.1, # Rouge 28: 0.1, # Rouge 12: 0.55, # Vert 13: 0.55, # Vert 4: 0.95 # Bleu

}


16 Muracciole Vincent & Lasne Fabrice | 12/02/2025

# Deep Learning avec tensor flow

# Fonction : Détecter l'index de la couleur

def detect_color_index():
red, green, blue = read_colors()
# Préparer les données pour le modèle TensorFlow nouvelle_couleur = [[red, green, blue]] # Forme attendue : liste de listes

# Faire la prédiction

prediction = modele.predict(nouvelle_couleur) print(f"Probabilités de la prédiction : {prediction[0]}") couleur_index = tf.argmax(prediction[0]).numpy() # Index de la classe prédite
print(f"Index de la couleur détectée : {couleur_index}")
return couleur_index

# Fonction : Positionner les servomoteurs

def position_servo(servo, position): servo.value = position
sleep(0.5)

# Fonction : Trier les M&M's

def tri_m_and_ms():
while True:
print("Déplacement en position de chargement...")
position_servo(servo_horizontal, SERVO_POSITIONS["horizontal"]["chargement"])

print("Déplacement en position de mesure...")
position_servo(servo_horizontal, SERVO_POSITIONS["horizontal"]["mesure"]) couleur_index = detect_color_index()

if couleur_index in SERVO_POSITIONS["vertical"]:
print(f"Tri pour la couleur d'index : {couleur_index}") position_servo(servo_vertical, SERVO_POSITIONS["vertical"][couleur_index]) print("Éjection...")
position_servo(servo_horizontal, SERVO_POSITIONS["horizontal"]["ejection"]) else:
print(f"Couleur inconnue (index {couleur_index}), éjection à une position par défaut.") position_servo(servo_vertical, 0) # Position par défaut ou d'échec

sleep(1) # Pause avant la prochaine itération

# Application pédagogique


17 Muracciole Vincent & Lasne Fabrice | 12/02/2025

# MERCI DE VOTRE ATTENTION


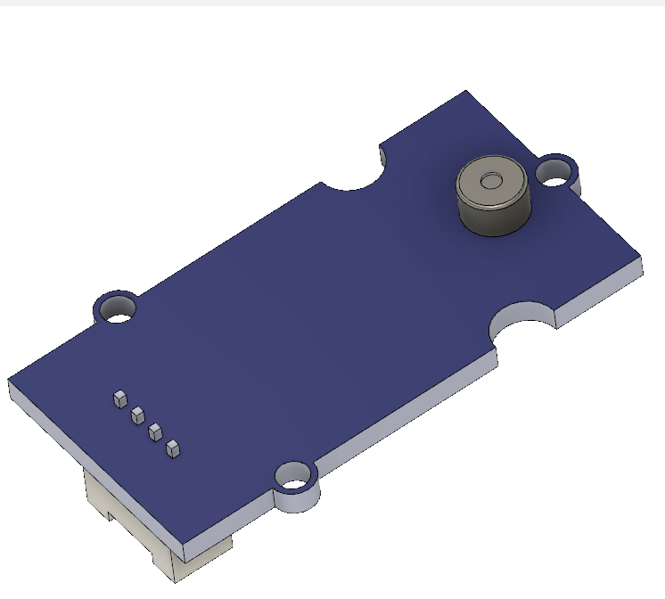
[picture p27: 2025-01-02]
SolidWorks/grove-inf-sensor.png

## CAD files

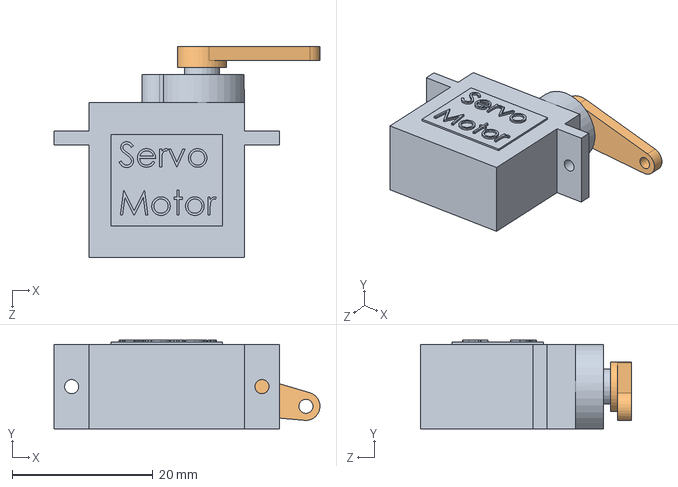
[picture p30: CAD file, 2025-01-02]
SolidWorks/Servo Moteur.SLDASM
37.7 x 12.6 x 30.0 mm
Servo Motor
Servo Motor Link

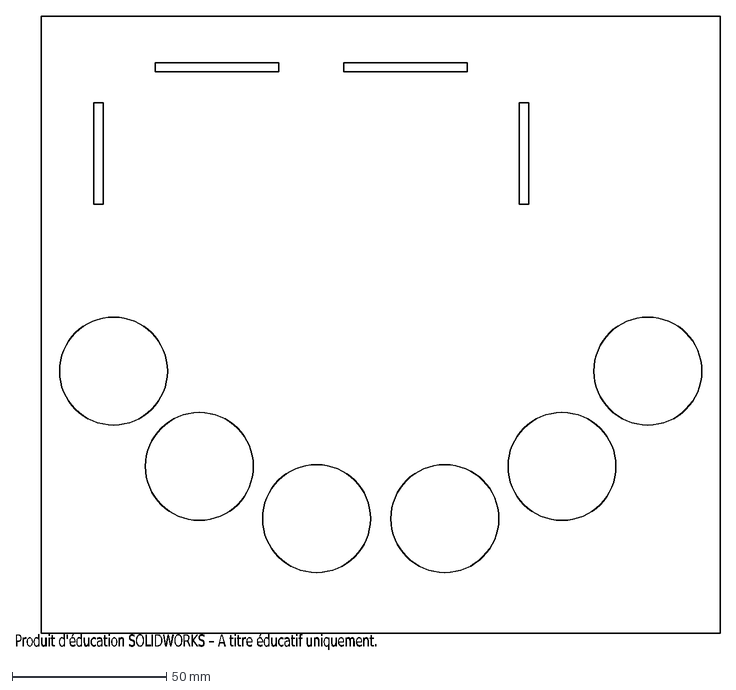
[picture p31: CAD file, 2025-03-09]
fichiers pièces à fabriquer/découpe laser/base.DXF
Produit d'éducation SOLIDWORKS – A titre éducatif uniquement.

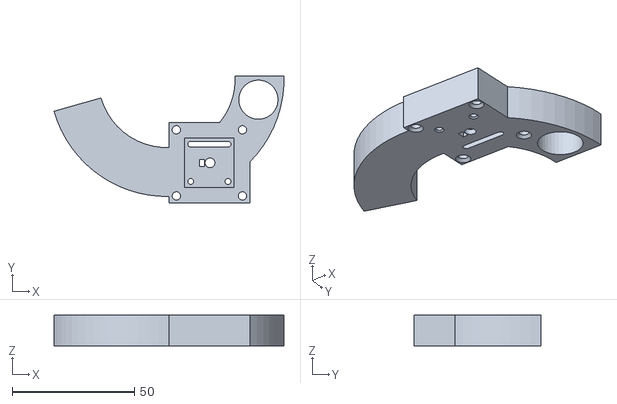
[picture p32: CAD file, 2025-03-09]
fichiers pièces à fabriquer/I3D/Support capteur.STL
94.0 x 52.1 x 12.5

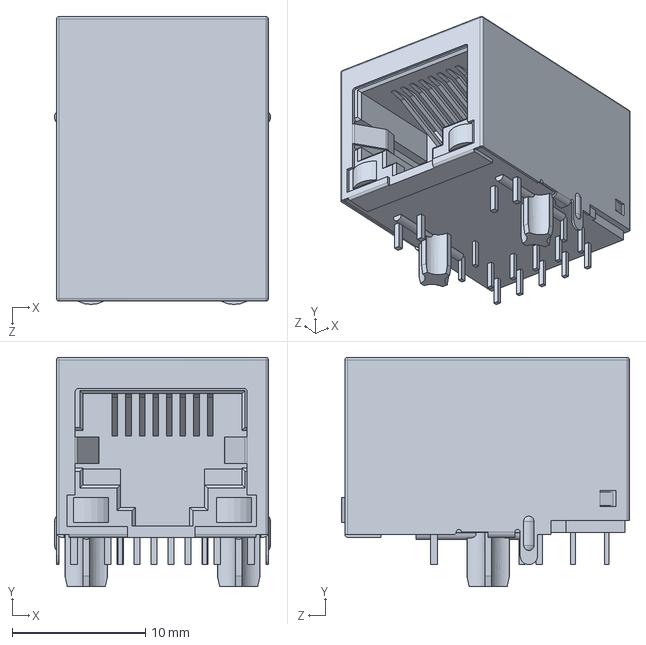
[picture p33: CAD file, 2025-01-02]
SolidWorks/Raspberry/Gigabit Ethernet Port, RPi4ModelB.SLDPRT
16.2 x 17.2 x 21.6 mm

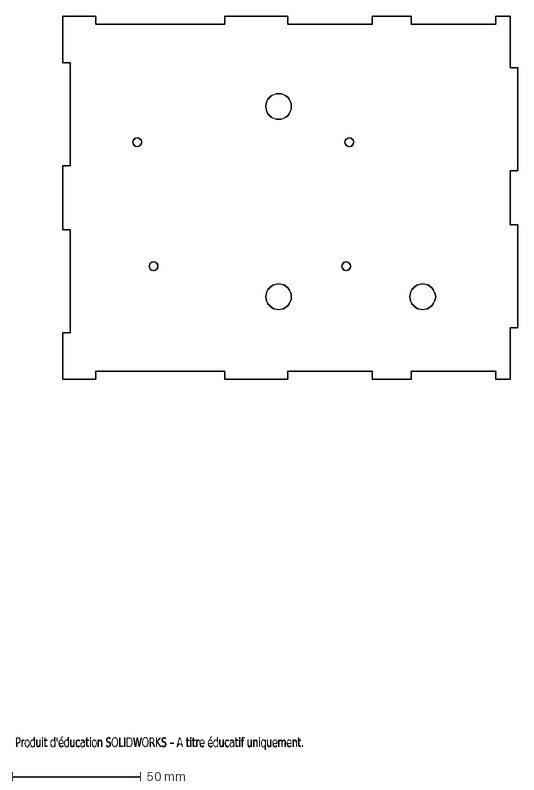
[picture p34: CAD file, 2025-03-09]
fichiers pièces à fabriquer/découpe laser/plaque arriere.DXF
Produit d'éducation SOLIDWORKS – A titre éducatif uniquement.

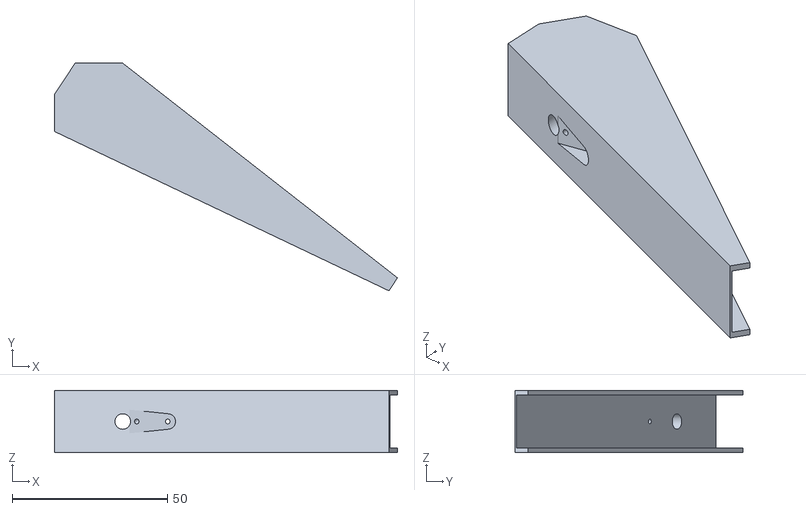
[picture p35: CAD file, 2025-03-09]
fichiers pièces à fabriquer/I3D/goulotte de sortie.STL
110.5 x 73.3 x 20.0

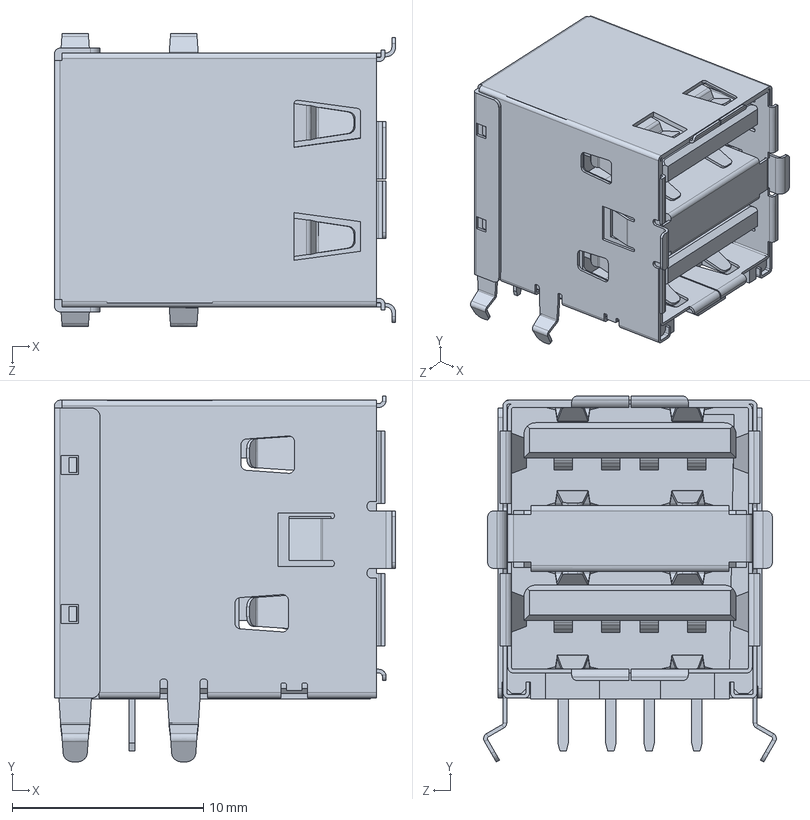
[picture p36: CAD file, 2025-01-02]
SolidWorks/Raspberry/2X USB2.0 PORTS, RPi4ModelB.SLDPRT
17.9 x 19.2 x 15.3 mm

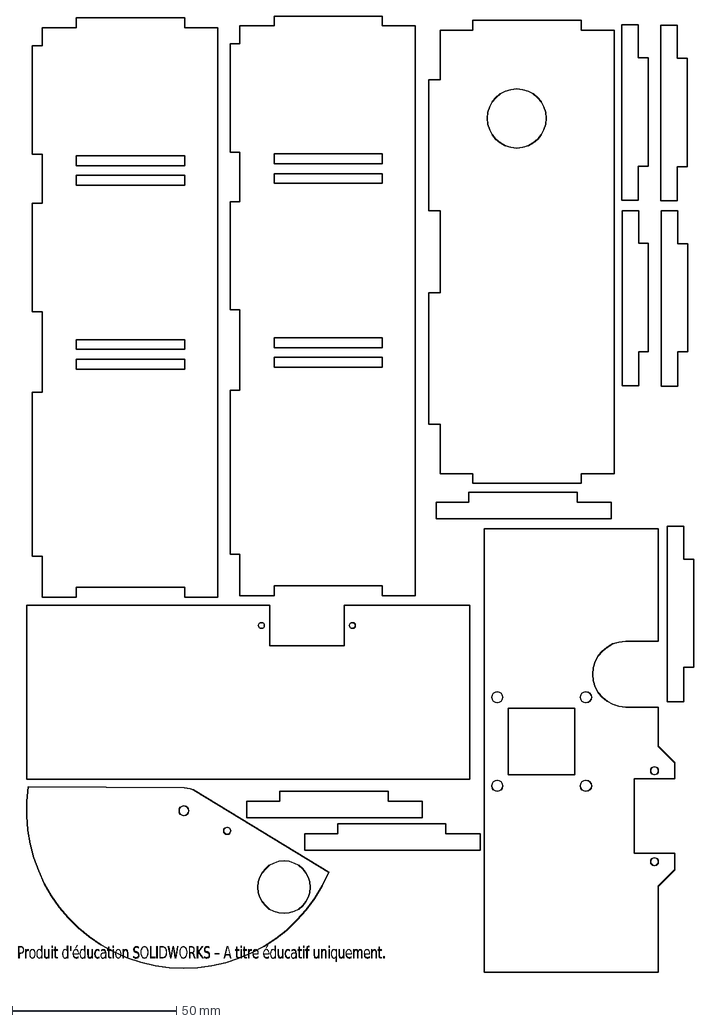
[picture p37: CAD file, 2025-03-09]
fichiers pièces à fabriquer/découpe laser/plaques horizontales.DXF
Produit d'éducation SOLIDWORKS – A titre éducatif uniquement.

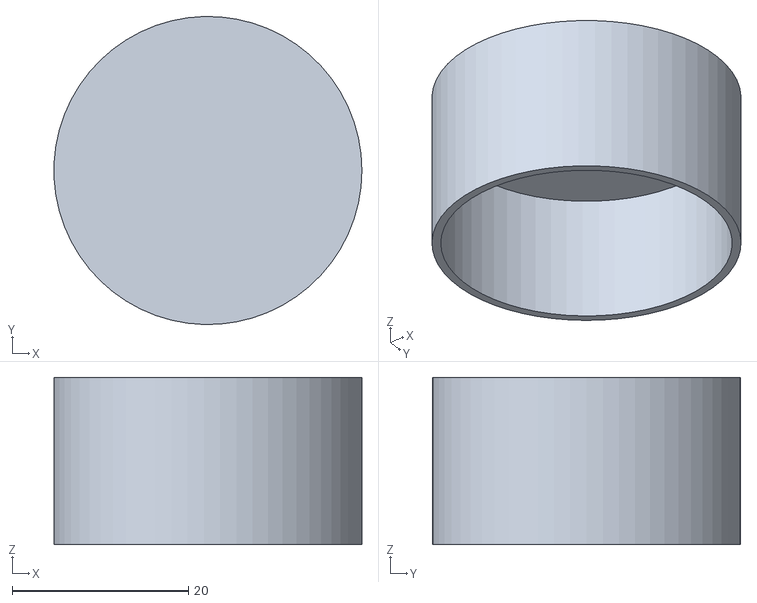
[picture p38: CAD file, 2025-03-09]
fichiers pièces à fabriquer/I3D/recepteur.STL
35.0 x 35.0 x 19.0

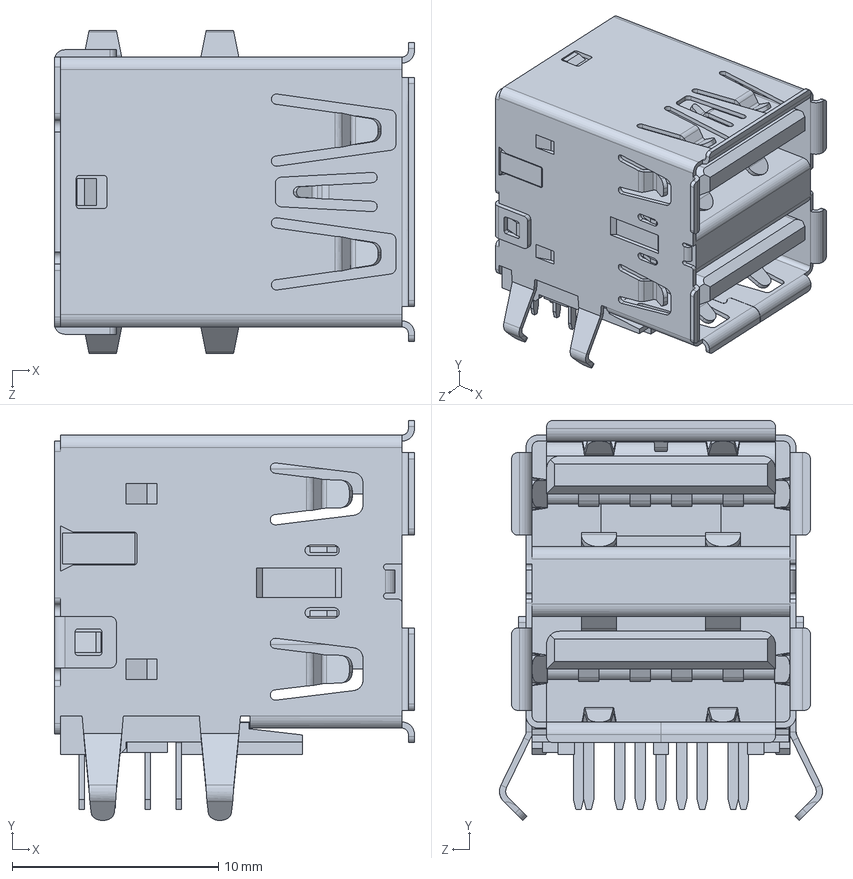
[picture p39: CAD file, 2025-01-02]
SolidWorks/Raspberry/2X USB3.0 PORTS, RPi4ModelB.SLDPRT
17.5 x 19.4 x 15.7 mm

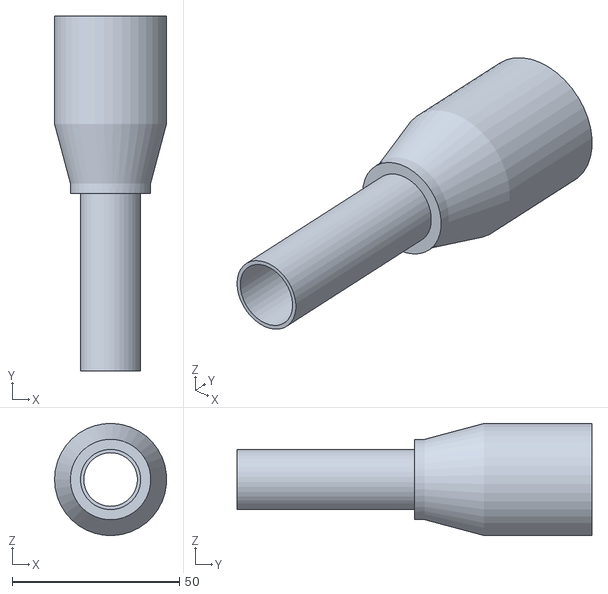
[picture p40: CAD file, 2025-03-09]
fichiers pièces à fabriquer/I3D/goulotte de stockage.STL
33.4 x 106.0 x 33.5

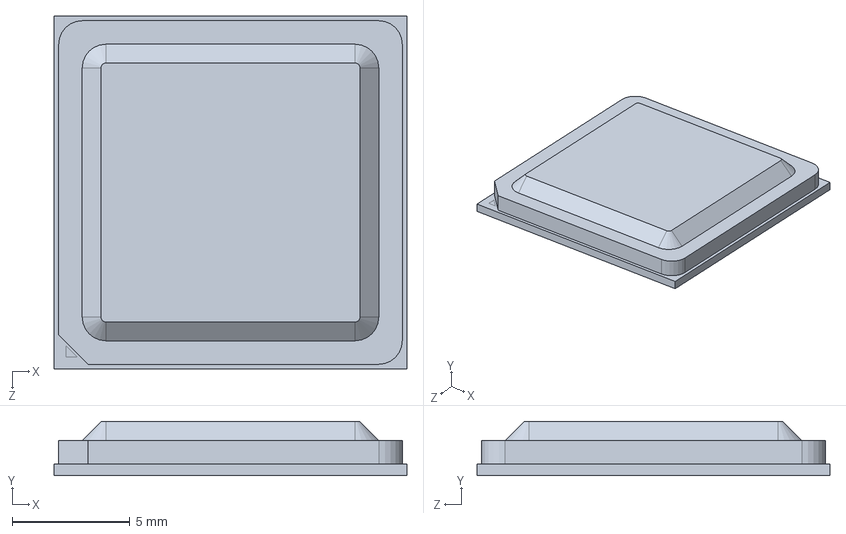
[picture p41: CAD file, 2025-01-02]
SolidWorks/Raspberry/Broadcom BCM2711B0 CPU, RPi4ModelB.SLDPRT
15.0 x 2.30 x 15.0 mm

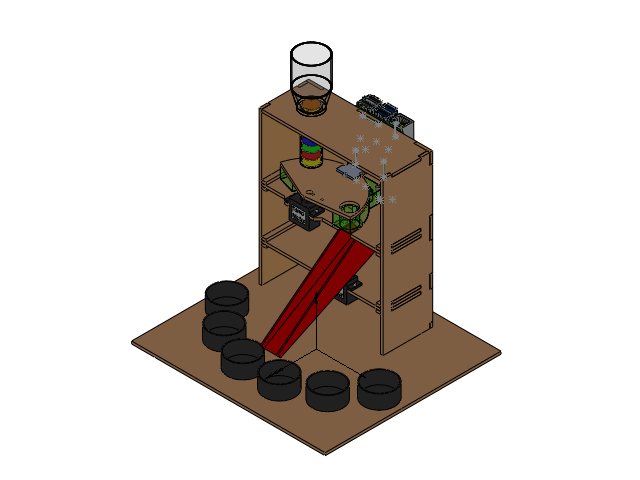
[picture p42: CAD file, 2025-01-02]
SolidWorks/trieur de smarties.SLDASM
base
recepteur x 6
Servo Motor x 2
Servo Motor Link x 2
plaque support trieur
plaque support separateur
Support capteur
plaque d'entrainement
goulotte de sortie
goulotte de stockage
smartie x 9
plaque haut
plaque gauche
plaque droite
plaque arriere
guide x 8
tcs34725
slotted countersunk flat head screw_iso x 4
plain washer normal grade a_iso x 12
hex nut style 1 gradeab_iso x 12
entretoise x 4
slotted cheese head screw_iso x 8
PCB, RPi4ModelB
Broadcom BCM2711B0 CPU, RPi4ModelB
2.54 mm DUPONT MALE PIN HEADER, POE, 2X2, RPi4ModelB
2.54 mm DUPONT MALE PIN HEADER, IO, 2X20, RPi4ModelB
Camera Connector, RPi4ModelB
Microphone Plug, RPi4ModelB
Display Connector, RPi4ModelB
Gigabit Ethernet Port, RPi4ModelB
Female Micro HDMI Connector, RPi4ModelB x 2
Female USB Type C Connector, RPi4ModelB
2X USB3.0 PORTS, RPi4ModelB
91D77 D9WHV 778K, 4 GB LPDDR4 SDRAM, RPi4ModelB
Cypress CYW43455 Wireless Module Cover, RPi4ModelB
SD Card Slot, RPi4ModelB
VIA VL805 PCIe USB 3.0 controller, RPi4ModelB
2X USB2.0 PORTS, RPi4ModelB
Broadcom BCM54213PE Gigabit Ethernet Transceiver, RPi4ModelB
MxL7704 Universal PMIC, RPi4ModelB
Grove-infrared-digital-temperature-sensor.step

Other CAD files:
SolidWorks/plaque gauche.sldprt
SolidWorks/guide.sldprt
SolidWorks/plaque droite.sldprt
SolidWorks/goulotte de sortie.sldprt
SolidWorks/Grove digital infrared temperature sensor.stl
SolidWorks/Grove-infrared-digital-temperature-sensor.step
SolidWorks/ISO - 4032 - M1.6 - D - N.sldprt
SolidWorks/ISO - 4032 - M3 - D - N.sldprt
SolidWorks/ISO 1207 - M1.6 x 8 - 8N.sldprt
SolidWorks/ISO 1207 - M2 x 8 - 8N.sldprt
SolidWorks/ISO 1207 - M3 x 16 - 16N.sldprt
SolidWorks/ISO 2009 - M3 x 20 - 20N.sldprt
SolidWorks/Raspberry/2.54 mm DUPONT MALE PIN HEADER, IO, 2X20, RPi4ModelB.SLDPRT
SolidWorks/Raspberry/2.54 mm DUPONT MALE PIN HEADER, IO, 2X40, RPi4ModelB.SLDPRT
SolidWorks/Raspberry/2.54 mm DUPONT MALE PIN HEADER, POE, 2X2, RPi4ModelB.SLDPRT
SolidWorks/Raspberry/91D77 D9WHV 778K, 4 GB LPDDR4 SDRAM, RPi4ModelB.SLDPRT
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
